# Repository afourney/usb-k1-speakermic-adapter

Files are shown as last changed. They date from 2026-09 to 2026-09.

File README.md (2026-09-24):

# USB K1 Speaker-Mic Adapter

A shoulder mic, a handful of breakout boards, and one USB cable. This adapter turns a Kenwood-style K1 radio speaker mic into a USB microphone, an amplified speaker, and two programmable push-to-talk buttons.

The excuse for building it was [Cabin Fever x86](https://github.com/afourney/cabin-fever-x86), a conversational text-adventure game played over a radio. If you're going to talk someone through an old text adventure, a proper shoulder mic feels like the right hardware. Squeeze the button, say your piece, and hear the reply through the same handset.

It also makes a satisfying physical interface for [Claude Code `/voice`](#claude-code) or [Teams](#microsoft-teams). Asking an agent to fix your code over a radio is optional. Saying “over” is between you and the transcription service.

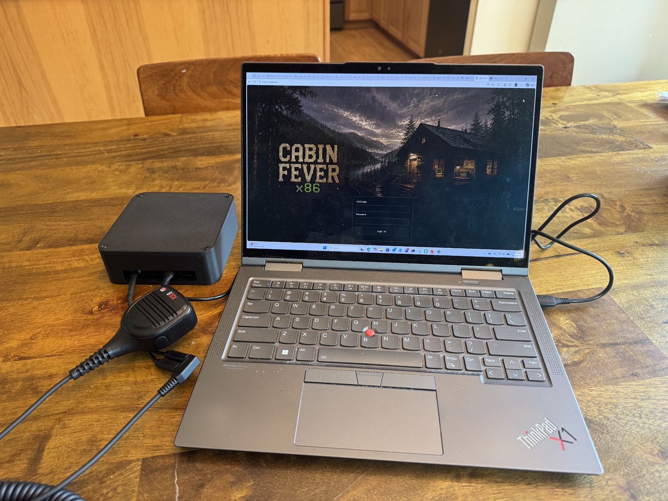
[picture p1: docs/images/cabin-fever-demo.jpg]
The finished adapter and BTECH speaker mic running Cabin Fever x86


*Ready to talk: the adapter and a BTECH QHM22D running Cabin Fever x86. Building with this mic? Read the [BTECH-specific wiring checks](docs/btech-qhm22d.md) first.*

## Video demo
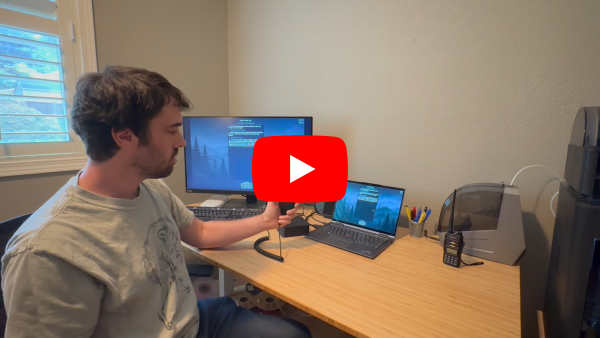
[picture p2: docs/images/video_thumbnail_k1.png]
Play Cabin Fever x86 with a real radio speaker mic! (https://www.youtube.com/watch?v=ixthcVkOpio)


## What's in the box?

The useful trick is to let ordinary USB devices do most of the work. A USB sound card handles microphone input and audio output. An LM386 module gives the little speaker enough drive to be heard. An Adafruit KB2040 running CircuitPython watches the two PTT buttons and presents them to the computer as keyboard keys. A tiny USB hub brings the audio and keyboard devices out through one cable. The supplied firmware sends **F13** from the main button and **Ctrl+Space** from the secondary button; both bindings are editable.

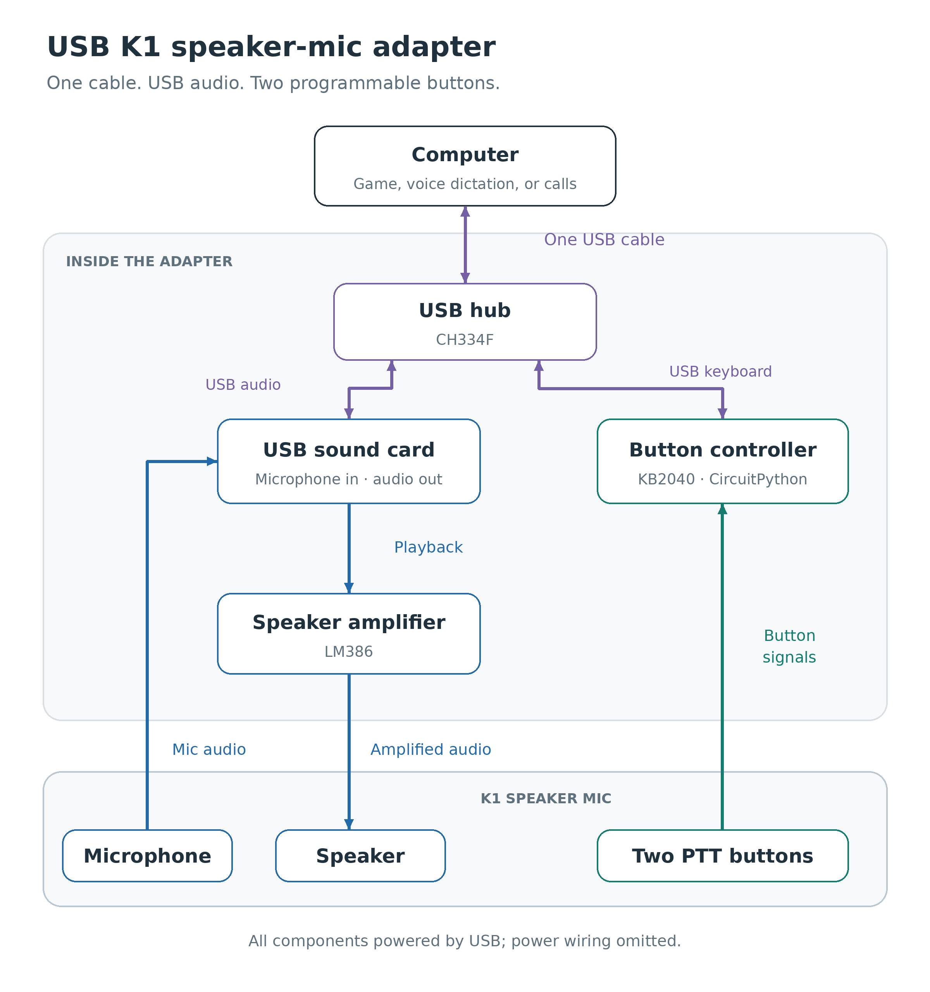
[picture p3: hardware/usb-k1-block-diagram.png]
Block diagram of the USB hub, sound card, LM386 amplifier, KB2040 button controller, and K1 speaker mic


*The sound card handles audio; the KB2040 turns button presses into keystrokes. Everything is powered from USB. Power wiring and individual connector contacts are left to the [schematic](#from-radio-accessory-to-usb-peripheral).*

## The K1 connector

The K1 connector has its roots in Kenwood's two-pin speaker/microphone interface: a 3.5 mm plug and a 2.5 mm plug mounted side by side. You'll find this Kenwood-style connection on handhelds from several manufacturers, notably the ubiquitous BaoFeng UV-5R. That shared connector gives us a ready-made supply of shoulder mics, earpieces, and other accessories to borrow for a USB project. [BTECH's compatibility list](https://baofengtech.com/product/qhm22d/) includes the UV-5R alongside models from Kenwood-style accessory families such as AnyTone, TYT, and Retevis.

A speaker mic already contains most of what we need: a microphone, a speaker, and a physical push-to-talk switch, all brought out through that pair of plugs. The audio connections are analog, and the PTT button closes a circuit. A compatible dual-PTT mic adds a second switch, giving us two independently readable buttons.

### K1 accessory pinout

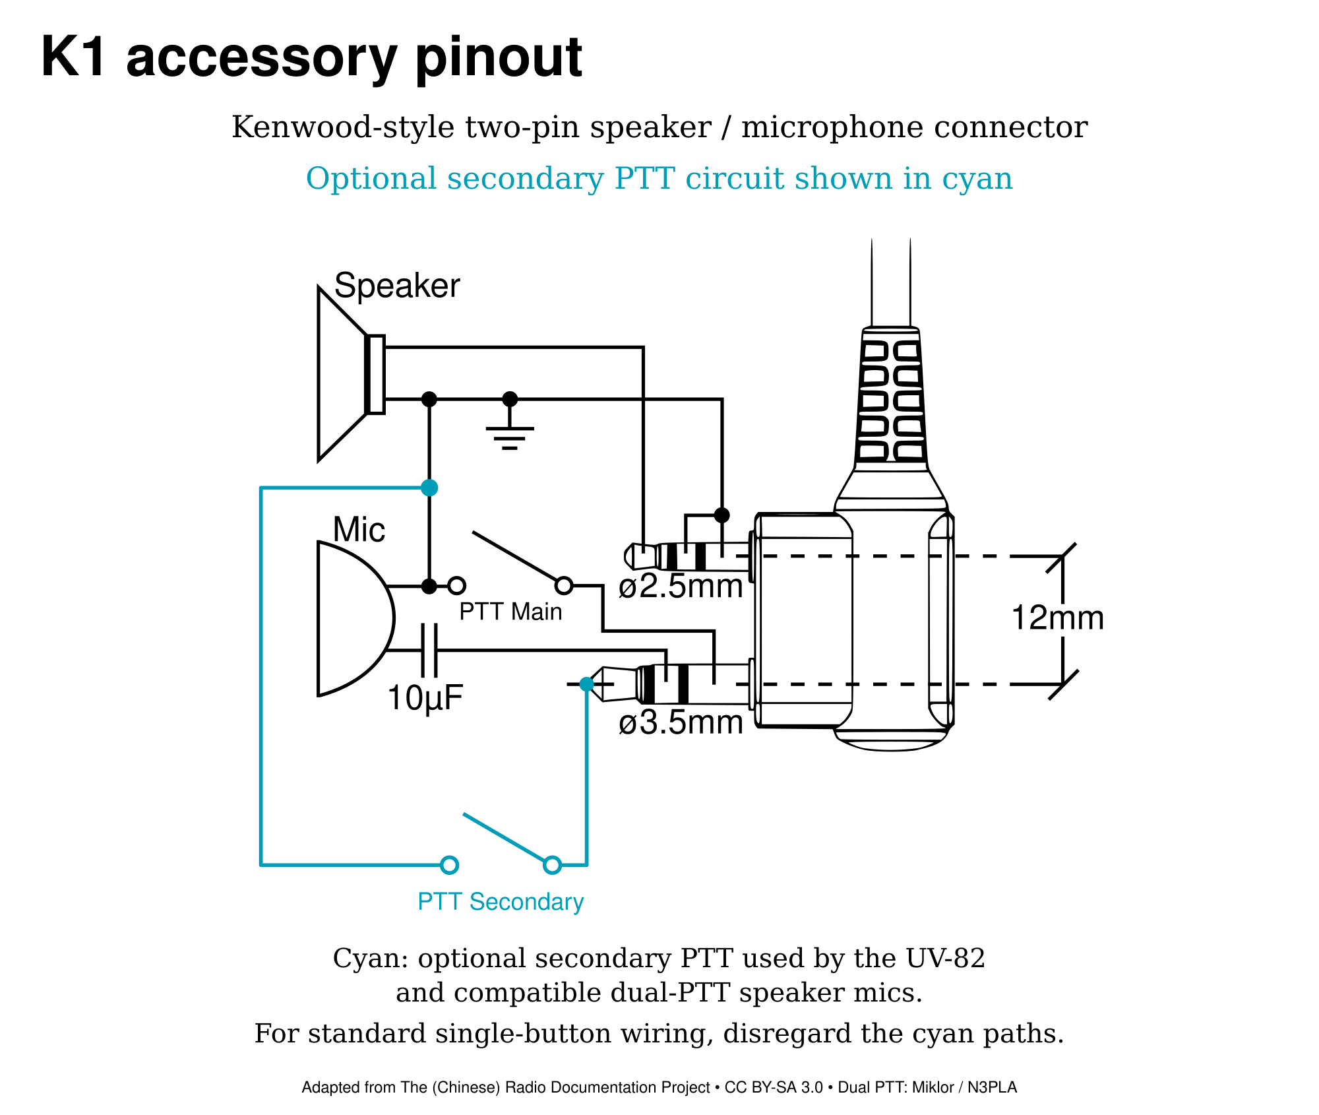
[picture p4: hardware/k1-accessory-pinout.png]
K1 accessory pinout: main PTT in black, optional secondary PTT in cyan


### From radio accessory to USB peripheral

Almost everything is already in place. The microphone can feed a suitable USB sound card's mic input, which supplies the electret bias. That leaves two jobs for the adapter.

First, the handset's **8 Ω speaker needs more drive than this USB sound card can provide directly**. It's a heavier load than a typical pair of headphones, and direct playback in this build was much too quiet. The LM386 module sits between the sound card's output and the speaker to supply the extra drive. It fits this build because it can drive a speaker with one side connected to **common ground**. This is important because the K1 handset shares that return between its speaker and PTT switches, ruling out bridge-output amplifiers such as the PAM8403, which actively drive both speaker terminals. Connecting such an amp's speaker “−” output to the adapter's common ground would short that output to ground.

The LM386 development boards used here come configured for approximately **200× voltage gain**. That's more than we need from a USB sound card and makes it easy to overdrive the amplifier. The LM386's default gain is **20×**; the board raises it with an external network between pins 1 and 8. See the [TI LM386 datasheet's gain-control section](https://www.ti.com/lit/ds/symlink/lm386.pdf#page=10). On the blue module used in this build, R1 is a 0 Ω jumper in the gain-boost network between pins 1 and 8. With power disconnected, **desolder R1 and leave its pads open**. This disconnects the boost network and returns the gain to **20×**. Check the board revision before modification since component labels are not universal.

While the sound card and amplifier take care of audio, we still need a way to report the handset's PTT switches to the computer—this is the second job of the adapter. Those buttons simply close electrical contacts that pull to ground. A microcontroller provides the missing link: it reads the switches and presents itself to the computer as a **USB HID keyboard**. Pressing a PTT button then looks like holding a keyboard key; releasing the button releases the key. Applications can use their [existing keyboard shortcuts](#using-it-with-applications) for push-to-talk, without needing a custom interface to the handset.

The **Adafruit KB2040** was chosen for a practical wiring detail: its **USB D+ and D− signals are broken out to accessible pads beside the USB-C connector**. That makes it straightforward to wire the USB data connection directly to the internal hub without soldering onto the connector's tiny contacts. Adafruit documents these pads in the [KB2040 pinout guide](https://learn.adafruit.com/adafruit-kb2040/pinouts). The board's RP2040 also provides native USB support and more than enough inputs for the two switches. Programming the board and choosing what each button sends are covered later in [firmware setup](#install-circuitpython-and-the-firmware).

The following wiring diagram shows the complete adapter, including the USB hub, sound card, LM386 module, KB2040, and K1 handset. The speaker mic block simplifies the handset's internal circuitry.

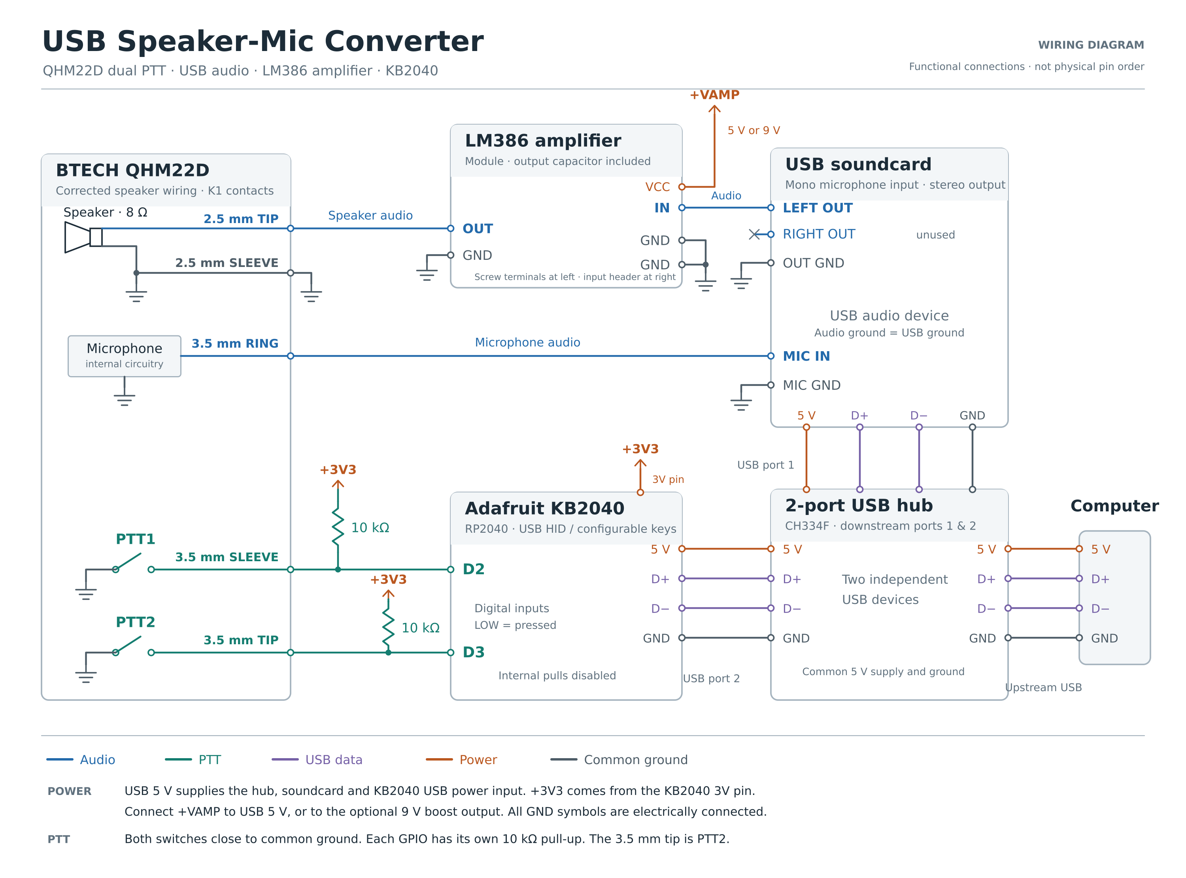
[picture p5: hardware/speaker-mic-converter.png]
USB speaker-mic converter wiring diagram


The build photo shows the LM386 at the top, the prototyping board in the middle, the KB2040 and USB hub below, and the separate USB audio adapter to the right. Follow the schematic and contact labels rather than copying wire colours from this overview.

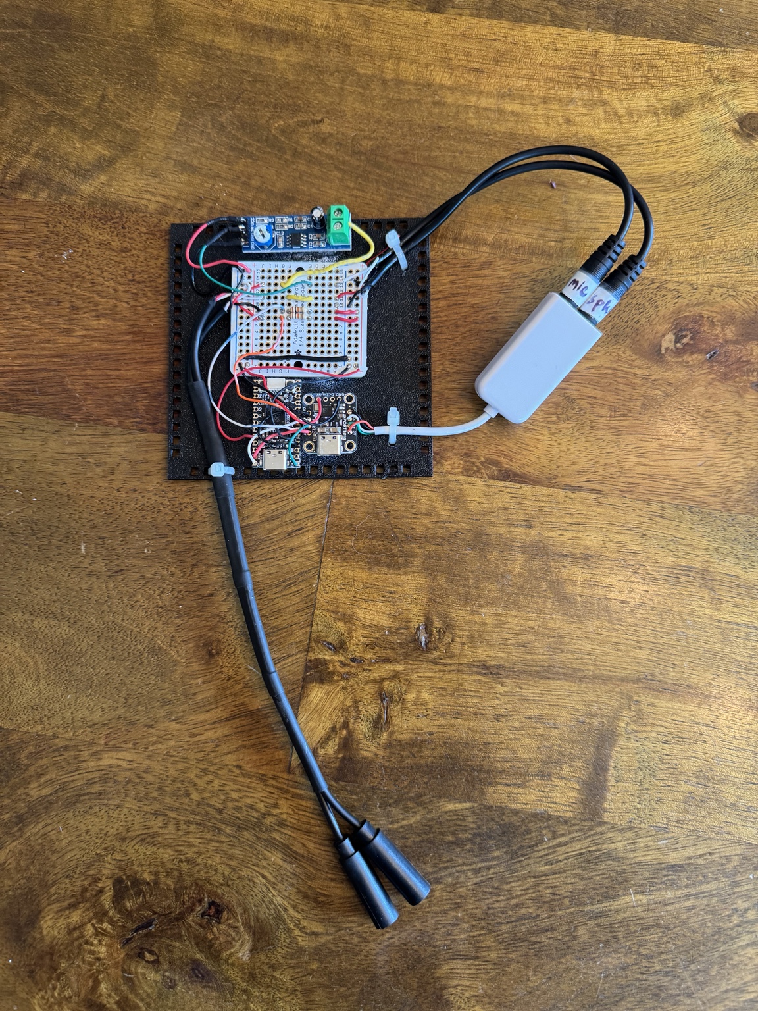
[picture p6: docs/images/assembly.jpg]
The module assembly before it is installed in the enclosure


## Parts and tools

Most of the work here is joining existing modules. These are the parts used in the documented build, with a reference part where the exact SKU wasn't recorded. Substitutions are fine if the electrical requirements match; check the board revision before copying a modification.

| Qty | Part | Purpose and selection notes |
| ---: | --- | --- |
| 1 | K1 Speaker Mic (e.g., [BTECH QHM22D dual-PTT speaker microphone](https://baofengtech.com/product/qhm22d/) · [Amazon](https://www.amazon.com/dp/B085HG7RX8)) | Kenwood K1-style two-plug connector, speaker, microphone, and one or two buttons. **Handset wiring can vary. [Test your handset before use!](#handset-wiring-check)** See the [BTECH-specific instructions](docs/btech-qhm22d.md) if using the QHM22D. |
| 1 | [Adafruit KB2040, product 5302](https://www.adafruit.com/product/5302) | RP2040 board for USB HID keyboard events. The supplied firmware uses its `D2`, `D3`, and `BUTTON` names. |
| 1 | [Adafruit CH334F Mini 2-Port USB Hub Breakout, product 5999](https://www.adafruit.com/product/5999) | Connects sound card and KB2040 to one upstream USB cable. Downstream connections are solder pads. |
| 1 | USB audio adapter with separate microphone and headphone jacks · [documented reference: Adafruit 1475](https://www.adafruit.com/product/1475) | Needs a microphone input suitable for an electret mic, including mic bias, and a ground-referenced headphone/line output. The exact SKU of the cabled adapter in the photos is unrecorded; do not assume its jack wiring from its appearance. |
| 1 | [LM386 audio amplifier module](https://protosupplies.com/product/lm386-audio-amplifier-module/) | The documented blue module has an input level trimmer and an output coupling capacitor. Use the capacitor-coupled output and common ground shown in the schematic. The prototype had its gain-setting **R1 removed**. |
| 2 | 10 kΩ resistors | One pull-up from each PTT input to the KB2040's regulated **3.3 V** output. Ordinary ¼ W resistors are sufficient. |
| 1 | [Adafruit Perma-Proto Quarter-sized Breadboard PCB, product 589](https://www.adafruit.com/product/589) | Carries the audio/PTT junctions and two resistors. One board is needed; the linked product is a pack of three. |
| 1 | One female **3.5 mm TRS** pigtail [Amazon](https://www.amazon.com/dp/B0C694NKJM) | Must expose all three contacts. If pigtails are not available, simply cut a short 3.5 mm extension cable and strip its wires. |
| 1 | One female **2.5 mm TRS** pigtail [Amazon](https://www.amazon.com/dp/B09V15J2MH) | Same as above. Cut an audio extension cable if pigtails are not available. |
| 2 | Short 3.5 mm male audio pigtails/breakouts [Amazon](https://www.amazon.com/dp/B0DMM3YFY1) | One for sound-card mic input; one for headphone output. This can be the other end of an extension cable if you cut one. |
| 1 | Upstream USB **data** cable | Computer to the hub's USB-C socket; choose the computer-end connector you need. |
| As needed | Heat-shrink, solder, cable ties, standoffs, screws | Keep USB data wiring short and paired. Insulate exposed connections and provide cable strain relief. |
| 1 | Nonconductive project box and mounting plate | Print the [supplied enclosure](docs/enclosure.md#print-the-enclosure), or size a project box around your assembled modules, plug bodies, cable bends, and lid clearance. |

The original diagram also shows an optional 9 V amplifier supply. **The instructions below use USB 5 V throughout.** A boost converter is unnecessary for the basic build; the prototype's 5 V/9 V comparison did not show a useful improvement for voice. Never feed 9 V into USB power, the KB2040, or a PTT input.

You will also need a multimeter with a low-ohms range, a soldering iron and flux, cutters/strippers, small screwdrivers, and a computer for copying files and testing USB audio. Fine tweezers and desoldering braid help with the amplifier's surface-mount gain resistor.

## Assembly Tips and Gotchas

### Handset wiring check

Handsets can be wired differently. Some BTECH QHM22D units, for example, have [been reported miswired](docs/btech-qhm22d.md) and need a repair before they can be used.

1. Unplug the handset from all equipment, including external earphones. Set the multimeter to resistance and touch the probes together to note the lead resistance.
2. Hold the main PTT button. Measure between the **3.5 mm sleeve** and **2.5 mm sleeve**: expect approximately **0 Ω**, plus probe/contact resistance.
3. Keep that same button held and move the probe from the **2.5 mm sleeve** to the **2.5 mm tip**. Expect the speaker-coil resistance—approximately **8–9 Ω** on the QHM22D used here.
4. Release the button and confirm that the sleeve-to-sleeve short disappears. For a compatible dual-PTT handset, also check **3.5 mm tip ↔ 2.5 mm sleeve**: pressing the secondary button should produce a near-zero reading, and releasing it should remove that short.

**Sleeve** means the metal contact nearest the cable; **tip** means the contact at the end of the plug. Use the numeric resistance reading: a continuity buzzer may beep for both 0 Ω and 8 Ω.

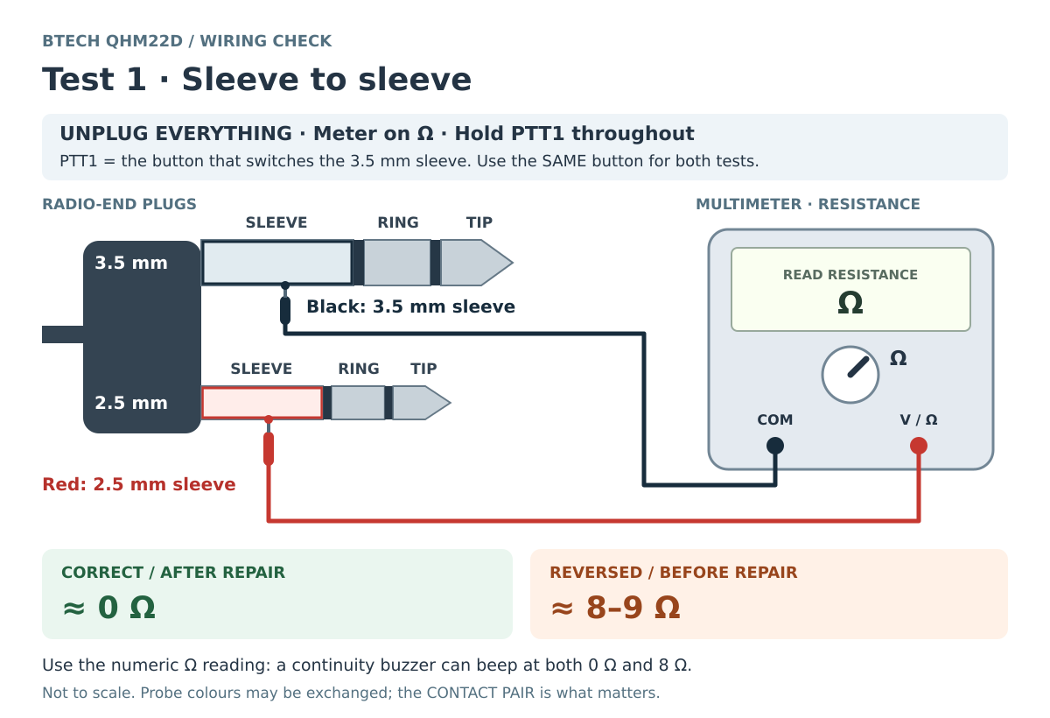
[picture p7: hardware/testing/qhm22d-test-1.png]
Test 1: probe the 3.5 mm sleeve and 2.5 mm sleeve while holding the main PTT


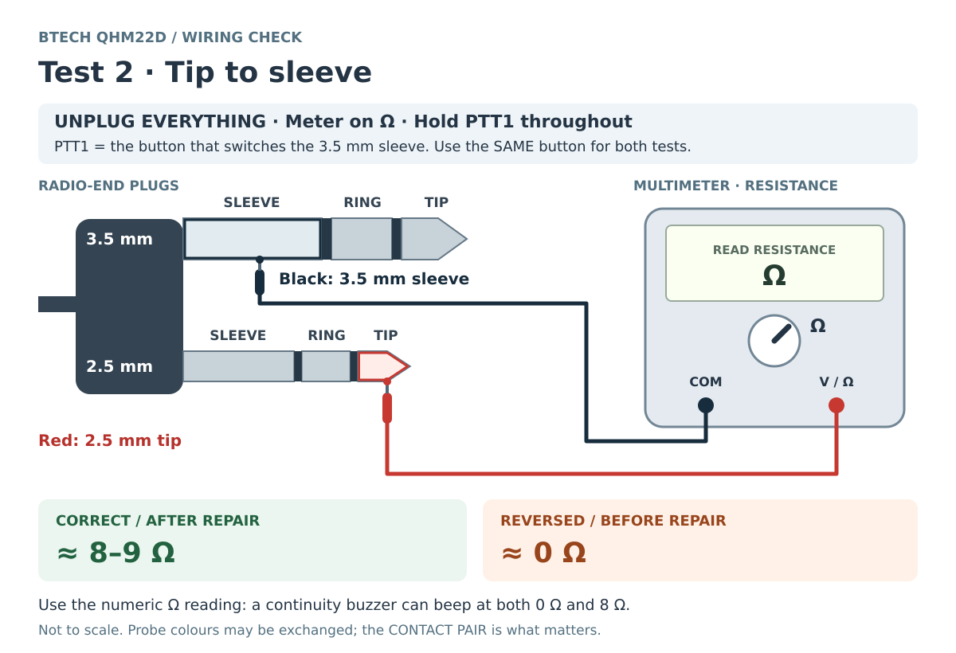
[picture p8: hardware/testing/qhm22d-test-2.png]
Test 2: keep the main PTT held and move the second probe to the 2.5 mm tip


*These diagrams show the BTECH QHM22D checks. If the two resistance readings are reversed, follow the [BTECH-specific repair instructions](docs/btech-qhm22d.md). Other handsets may have different speaker resistance or switching; investigate unexpected results before connecting them.*

### USB sound card preparation

The Adafruit CH334F Mini hub does not have any sockets for the client USB devices. The sound card and KB2040 must be wired to the hub's downstream pads. With USB disconnected, prepare the sound card by clipping the original USB cable and stripping the wires. Identify the four wires by continuity; use colour only as a clue. In my device, the colours were red = 5 V, black = GND, green = D+, and white = D−. It is important to check your own device, as the colours are not guaranteed to be the same. To do this, strip the wires on the connector end as well, and check continuity between the wires and the USB contacts. Use the following pinout to identify the contacts:

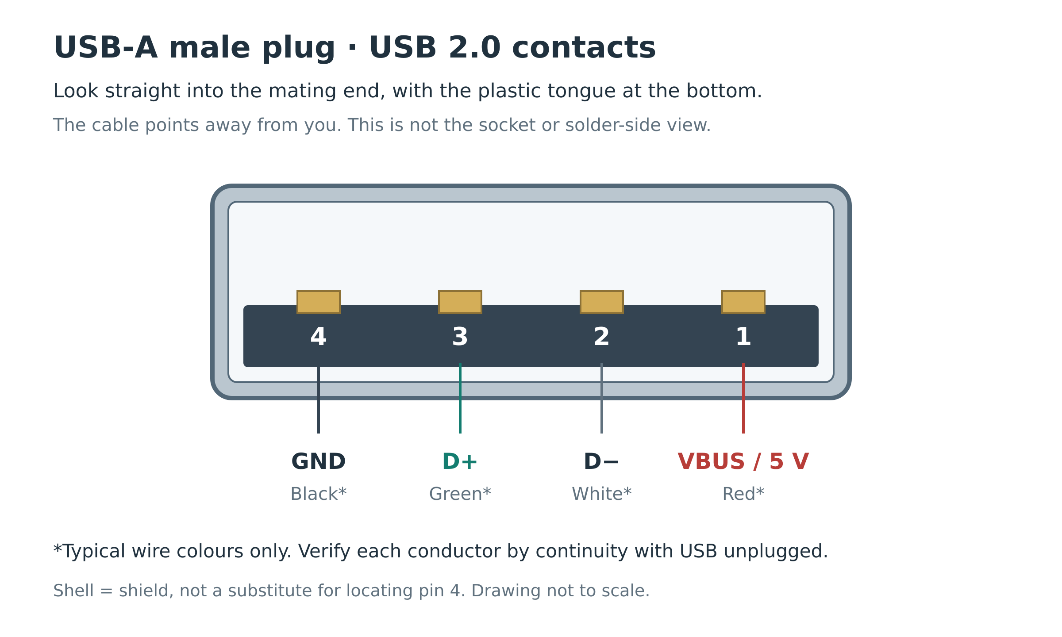
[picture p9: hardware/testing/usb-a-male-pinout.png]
USB-A male plug pinout, viewed into the mating end with the plastic tongue at the bottom


*View the male plug straight into its mating end, with the plastic tongue at the bottom and the cable pointing away from you. From left to right: pin 4 = GND, pin 3 = D+, pin 2 = D−, pin 1 = VBUS (5 V). Colours are typical, not guaranteed. Pin assignments and orientation follow the [USB 2.0 specification](https://www.usb.org/document-library/usb-20-specification), Table 6-1 and Figure 6-9.*

When connecting the sound card to the hub, keep the wires short and the D+/D− data pair twisted together. Do the same when connecting the KB2040 to the hub.

### Don't mix up your positive rails!

When wiring all the modules, note that all components share a common ground, but there are two positive rails: the USB 5 V and the KB2040's regulated 3.3 V. The LM386 module, USB hub, and USB devices (sound card and KB2040) are powered from the USB 5 V. On the KB2040, the `RAW` pin is on the USB-derived power rail, after the protection diode and fuse by default; see the [power pinout](https://learn.adafruit.com/adafruit-kb2040/pinouts). The KB2040 board has a 3.3 V regulator that then powers the onboard RP2040 microcontroller. **The two PTT inputs are pulled up to the KB2040's 3.3 V rail, <u>not the USB 5 V.</u>**

### Reduce excessive gain

As explained above, the LM386 development board starts at approximately **200× gain**. With power disconnected, **desolder the 0 Ω R1 jumper and leave its pads open** to disconnect the gain-boost path and return the LM386 to **20× gain**. Then set the onboard trimmer pot to about 1/3–1/2 of its range, and test the audio. If the sound is still harsh or distorted, reduce the trimmer further. The trimmer is not a gain control; it simply reduces the input level to the amplifier.

## Install CircuitPython and the firmware

Once CircuitPython is installed, changing what the buttons do is a text-file edit. The first flash takes a few more steps:

1. Download the stable [CircuitPython UF2 for **Adafruit KB2040**](https://circuitpython.org/board/adafruit_kb2040/).
2. With the board unplugged, hold **BOOT** while connecting its USB data cable. Release BOOT when the `RPI-RP2` drive appears. If the board is already wired to the hub, use that connection instead of a second USB cable.
3. Copy the `.uf2` file to `RPI-RP2`. The board restarts and exposes a drive named `CIRCUITPY`.
4. Download the [Adafruit CircuitPython library bundle](https://circuitpython.org/libraries) matching the major CircuitPython version in `CIRCUITPY/boot_out.txt`.
5. Copy the bundle's entire `adafruit_hid` folder into **`CIRCUITPY/lib/adafruit_hid/`**.
6. Copy [firmware/code.py](firmware/code.py) to **`CIRCUITPY/code.py`**. It belongs in the drive root, not inside `lib`. On Windows, show file extensions and check that it is not named `code.py.txt`.
7. Saving the file normally restarts the program. Later edits require only saving `code.py`, not flashing the UF2 again.

The supplied configuration is:

```python
PTT1_KEY = Keycode.F13
PTT2_KEY = (Keycode.LEFT_CONTROL, Keycode.SPACE)
BOOT_ALIASES_PTT1 = True
USE_INTERNAL_PULLUPS = False
DEBOUNCE_SECONDS = 0.020
POLL_SECONDS = 0.002
LOG_CHANGES = True
```

| Input | While held | On release |
| --- | --- | --- |
| PTT1 / D2 | F13 | Releases F13 |
| PTT2 / D3 | Left Ctrl + Space | Releases the chord |
| Onboard BOOT, after normal startup | F13 | Releases F13 when D2 is also released |

Change the keyboard mapping by adjusting `PTT1_KEY` and/or `PTT2_KEY`. For example, `PTT2_KEY = Keycode.SPACE` or `PTT2_KEY = Keycode.F14`. A Python tuple (e.g., `(Keycode.LEFT_CONTROL, Keycode.SPACE)`) represents a chord where both keys are held together. Here, pushing the button sends Ctrl+Space; releasing it releases both keys. The onboard BOOT button aliases PTT1 and is useful for testing the firmware before assembly or before any handset is attached. NOTE: as usual, holding BOOT at startup enters the bootloader.

Each input is debounced for 20 ms. When a PTT button is held, it holds keys as a keyboard would. The operating system may generate key-repeat events.

**External pull-ups are required by the default firmware.** For a temporary test of a bare KB2040 without the resistors, set `USE_INTERNAL_PULLUPS = True` before running it; restore `False` when both external 10 kΩ resistors are installed. Otherwise unconnected inputs float and can send unintended keys.

## Test the complete adapter

Now it's time to verify that the adapter works as intended. Start by checking the buttons and audio separately, then test them together with an application.

### Buttons first

1. Open the [W3C Keyboard Event Viewer](https://w3c.github.io/uievents/tools/key-event-viewer.html) and focus its input.
2. Hold PTT1: expect F13 down. Release it: expect F13 up. F13 does not type a visible character.
3. Hold PTT2: expect Control and Space with Ctrl active. Release it and check that **both** keys are released.
4. Hold both handset buttons; release them in each order. Each input should release without interfering with the other.

If these checks fail, use the [serial-console guide](docs/serial-console.md) to check the firmware's log messages for errors.

### Then audio

1. Select the USB sound card as the computer's input and output device, or select it explicitly in the application. Device names vary.
2. Record a short voice sample.
3. Start playback at low computer volume and low amplifier level. Slowly raise the level while listening to speech.
4. If the speaker sounds harsh or buzzy, turn down the computer output or amplifier input trimmer. The prototype was clear for voice but could clip on music.

## Mount it in an enclosure

The last component is a box to hide our wiring sins and protect the modules. The [enclosure folder](enclosure) includes STLs for the body, lid, and mounting plate with standoffs, plus a [Bambu Lab P1S 3MF project](enclosure/K1%20Adapter%20Box.3mf). You can also find the enclosure on [MakerWorld](https://makerworld.com/en/models/3343715-usb-k1-speaker-mic-adapter-enclosure#profileId-3799259). Test the complete assembly before closing it up. Mount each board on an insulating plate or standoffs, secure the audio adapter, and strain-relieve the USB and K1 cables. Leave room for the plug bodies and access to the amplifier trimmer and KB2040 reset/BOOT buttons. Keep solder joints clear of screws and the lid.

| Open enclosure | Finished cable entry |
| --- | --- |
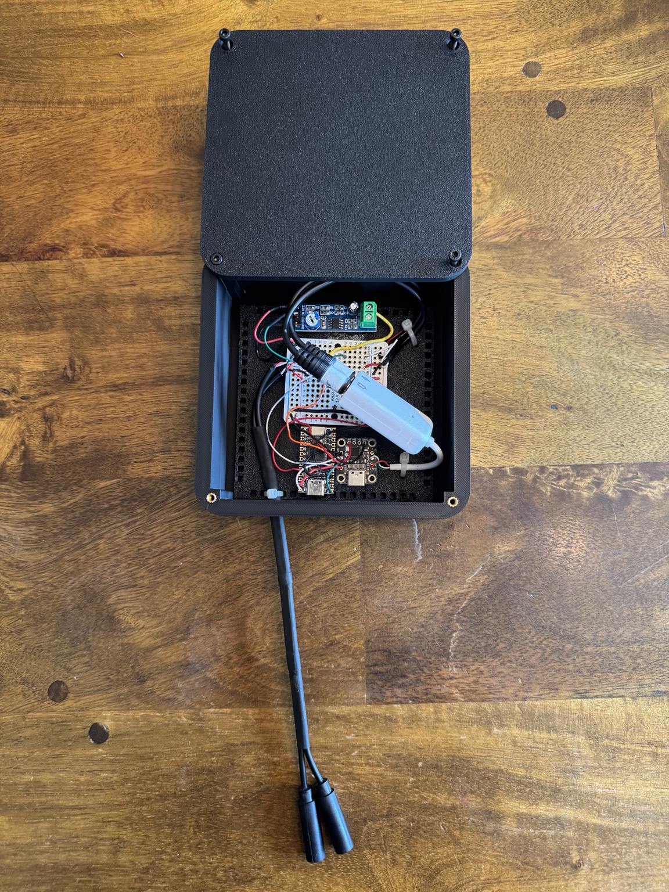
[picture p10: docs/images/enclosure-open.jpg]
Modules mounted inside the enclosure
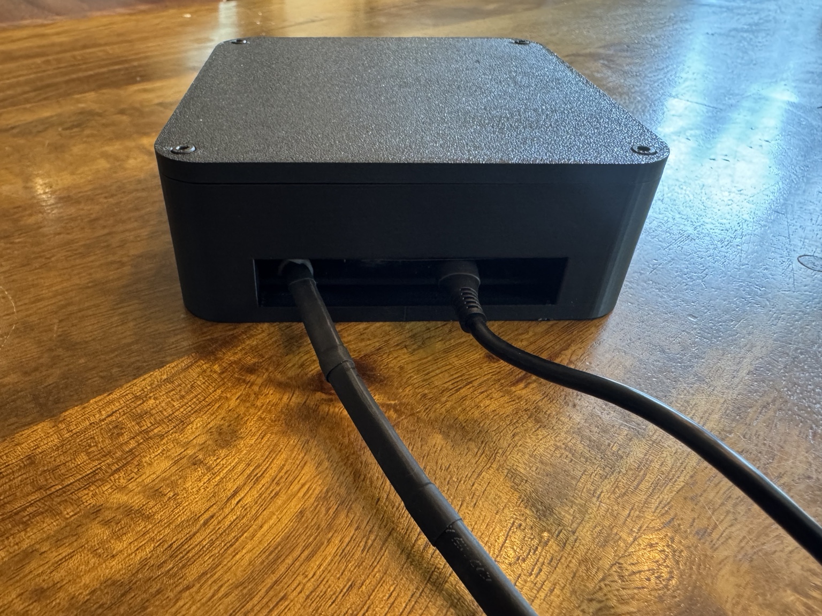
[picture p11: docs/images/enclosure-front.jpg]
Front opening with K1 breakout and USB cable
|  |  |

See [enclosure and mounting notes](docs/enclosure.md) for print settings and fitting the electronics. After mounting, repeat the button and audio tests while gently moving the cables. Nothing should disconnect, crackle, or generate a button press from cable movement.

## Using it with applications

At this point the computer sees audio hardware and a keyboard. Choose the USB sound card for audio, then tell the application what its PTT key should do. The application decides when to listen; the adapter supplies the sound and button presses.

### Cabin Fever x86

Use the adapter with [Cabin Fever x86](https://github.com/afourney/cabin-fever-x86). Select the USB microphone, grant the browser microphone permission, and route playback to the USB sound card. Match the handset's firmware binding to the game's current PTT control. Check that releasing the button ends the recording before a full session.

### Claude Code

Select the USB microphone as the host's input, enable `/voice hold`, and focus the prompt. Claude Code's default dictation key is Space; to test that path, set `PTT2_KEY = Keycode.SPACE` in the firmware. In hold mode, terminal key repeat must be enabled. See the official [voice dictation guide](https://code.claude.com/docs/en/voice-dictation).

To try the repository's **default Ctrl+Space** instead, merge the following into `~/.claude/keybindings.json` in the environment running Claude Code:

```json
{
  "bindings": [
    {
      "context": "Chat",
      "bindings": {
        "ctrl+space": "voice:pushToTalk"
      }
    }
  ]
}
```

This is a configuration example, **not a confirmed fix for Windows Terminal/WSL2**. Ctrl+Space did not work reliably in the original setup. Check terminal shortcut interception and the key received by Claude Code; use `/keybindings` and the [keybinding documentation](https://code.claude.com/docs/en/keybindings). A native browser receiving the HID chord does not prove that the terminal forwards it correctly. For WSL, also verify that its audio input works through WSLg.

#### Auto-submit on release

To send your dictated prompt when you release the PTT button, merge this into `~/.claude/settings.json` in the environment running Claude Code (inside WSL if that is where you run it). Keep any other settings already in the file:

```json
{
  "voice": {
    "enabled": true,
    "mode": "hold",
    "autoSubmit": true
  }
}
```

Hold the configured PTT button, speak, then release it. Claude Code finalizes the transcript and submits the prompt automatically if the transcript contains **at least three words**. Shorter transcripts stay in the input for manual submission with Enter. Set `"autoSubmit": false` to review every dictated prompt before sending. See the official [hold-to-record and auto-submit instructions](https://code.claude.com/docs/en/voice-dictation#hold-to-record).

### Microsoft Teams

Select the USB mic and speaker in Teams, then check the installed client's keyboard shortcuts for its press-and-hold temporary-unmute action. The firmware's Ctrl+Space binding is intended for clients that offer that shortcut. Test from a muted meeting with the intended window focus: hold to speak, release, and verify that the mute indicator returns. A single shared keybinding working in both Teams and Claude Code has **not been established for this build**.

## Troubleshooting

| Symptom | Check |
| --- | --- |
| Speaker works, but PTT fails or changes when headphones are inserted into the handset | For the BTECH QHM22D, follow the [wiring-test and repair guide](docs/btech-qhm22d.md). For other handsets, verify their wiring against the pinout. |
| Random key presses, or a button appears held | Both 10 kΩ pull-ups must connect to 3.3 V; confirm handset ground, correct socket contacts, and that the plugs are fully seated. |
| PTT is always active | Check that the K1 3.5 mm sleeve was not mistaken for common ground. |
| BOOT works but handset buttons do not | Check D2/D3 versus A2/A3, connector continuity, pull-ups, and each switch's resistance to ground. |
| Nothing appears over USB | Use a data cable; inspect upstream/downstream assignment, D+/D−, 5 V, and GND. Test each device separately. |
| Audio or keyboard disappears when the speaker gets loud | Reduce playback level; investigate supply sag, shorts, poor ground connections, and the USB source's current budget. |
| Speaker is extremely quiet | Check that playback passes through the powered LM386 and its level trimmer is not at minimum. |
| Harsh or distorted playback | Lower sound-card output and amplifier input level; confirm the intended gain modification. |
| No mic signal | Check the selected USB input, app permission, mic bias, K1 ring mapping, and whether the handset gates audio with its buttons. |
| Music is missing instruments or voices | Only the left channel is wired. Enable host mono output. |
| Firmware import error | Install the matching `adafruit_hid` folder under `CIRCUITPY/lib/`. |
| Keys work in a browser but not Claude Code | Check terminal key translation/interception and Claude Code's active binding. |
| Serial console is blank or PuTTY beeps | Follow [serial-console setup](docs/serial-console.md), including selecting Serial on the Session page. |

## References

### K1 diagram sources

- [The (Chinese) Radio Documentation Project's original SVG](https://github.com/radiodoc/uv-5r/blob/master/assets/images/kenwood-2pin-headset.svg) — Source artwork for the K1 diagram, licensed under CC BY-SA 3.0; the adapted PNG and SVG retain that license. This adaptation removes the +5 V label, adds the cyan secondary-PTT circuit, and revises the labels and captions.
- [The project's UV-5R manual](https://radiodoc.github.io/uv-5r/) — Original publication containing the accessory diagram.
- [Miklor's UV-82 technical notes](https://www.miklor.com/COM/UV_Technical.php) — Explains UV-82 dual-PTT operation and wiring.
- [Walt N3PLA's circuit diagram](https://www.miklor.com/COM/images/dualPTT-N3PLA.jpg) — Circuit reference for the added secondary-PTT wiring.
- [Kenwood's TH-F6A/TH-F7E manual, printed page 45](https://kasc.kenwood.com/files/images/products/product_id_268/file_category_10/TH-F6A_F7E_inst.pdf#page=50) — Corroborates the conventional speaker, microphone, and main-PTT contacts.
- [BaoFeng Tech's UV-82HP manual, printed page 19](https://baofengtech.com/wp-content/uploads/2020/09/UV82HP_Manual_ReducedSize.pdf#page=26) — Documents upper/lower-channel PTT operation; its generic accessory drawing does not show the second switch.

## Copyright and license

Copyright © 2026 Adam Fourney.

Licensed under the [MIT License](LICENSE), except for the adapted K1 accessory diagram, which retains its CC BY-SA 3.0 license as noted above. Please retain the copyright and license notices when redistributing this work.

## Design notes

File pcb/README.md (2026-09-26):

# K1 Carrier - Revision C (80 x 80 mm)

Open `kicad/k1-carrier-rev-c.kicad_pro` in KiCad 10. This is a standalone snapshot of the 80 x 80 mm, two-layer Revision C engineering project. Earlier revisions are not needed or included. See `PROJECT-SNAPSHOT.md` for package contents and Git tracking notes. Connector assignments are unchanged from Revision B; the modules and mounting holes have been repositioned for the smaller outline.

KiCad 10.0.6 checks: 0 ERC violations, 0 DRC violations, 0 unconnected pads, and 0 schematic-parity issues. Reports are saved in `preview/`. The schematic and assembly previews accompany the editable project. These checks do not replace the prototype release checks below.

## Connector Configuration (Retained From Revision B)

| Reference | Assignment |
|---|---|
| J1 | Board-mounted USB-A receptacle, Molex 67643-0910, replacing the USB wire pads |
| J2 | Sound-card microphone pigtail, moved to the right perimeter |
| J3 | Sound-card headphone-left pigtail, beside J2 |
| J4 | Six-circuit, right-angle Micro-Fit 3.0 header, Molex 43045-0600, replacing both K1 pigtail connectors |
| J5 | Retired; its K1 contacts are now in J4 |
| J6 | One 1x4, 2.54 mm interface: VCC, IN, GND, GND, replacing separate amplifier power and input connections |
| J7 | Retired; its audio input is now J6 pin 2 |
| J8 | LM386 capacitor-coupled output and optional ground, located to the left of R1/R2 |

The two PTT pull-ups remain 10 kohm to the **KB2040 3V / 3.3 V output**, not USB 5 V. Both switches continue to pull D2/D3 to common ground. Existing firmware assignments are preserved.

## Placement

The CH334F module's USB-C socket faces the top edge. The KB2040 sits below and to its right. The USB-A receptacle faces the right edge, with both sound-card audio pigtails below it. The Micro-Fit faces the bottom edge. The LM386 lies horizontally in the lower mounting area, with the combined input/power harness to its left. J8 sits above the amplifier, to the left of R1/R2. The amplifier outline has moved 8 mm right, leaving 10.5 mm from the J6 pad centerline to the module's left edge.

The USB-A socket is intended to face an **internal enclosure bay**, not necessarily an external wall. Allow room to the right of the carrier for the complete sound adapter, its plugs and cable bends. A short USB extension can relocate the adapter. No sound-card body dimensions are assumed. The enclosure footprint will need clearance beyond the carrier's 80 x 80 mm outline.

Leave clearance below J4 for its mating housing, wires and latch release. The Micro-Fit is not a panel-mount connector; strain-relieve the K1 harness at the enclosure. The LM386 mounting area is for electrically insulating double-sided foam mounting tape, not direct metal-to-PCB contact. Choose sufficient thickness to keep underside solder joints clear of the carrier, and check adhesion and temperature suitability on the actual module. The four amplifier tie-down holes have been removed; the four enclosure mounting holes remain.

The upper-right mounting hole is inset to clear the USB-A body. Relative to the board's upper-left corner, the four enclosure mounting holes are at (4,4), (58,4), (4,76), and (76,76) mm. J4 pin 6 and U2 pin 4 use solid ground-plane connections rather than thermal spokes.

## Connections

### J4: Entire K1 Harness

Use Molex **43025-0600** six-circuit receptacle housing and suitable Micro-Fit female crimp contacts/pre-crimped leads. Select contacts for the actual wire gauge and insulation diameter. Read the numbered cavities: the cable mating view and PCB top view are mirrored. Do not infer numbering from wire colours or the order in a photograph.

| Pin | K1 contact | Signal |
|---:|---|---|
| 1 | 3.5 mm tip | PTT2 / D3 |
| 2 | 3.5 mm ring | Microphone |
| 3 | 3.5 mm sleeve | PTT1 / D2; NOT ground |
| 4 | 2.5 mm tip | Speaker |
| 5 | 2.5 mm ring | Unconnected on carrier; may be left unpopulated |
| 6 | 2.5 mm sleeve | Common ground |

### J6: LM386 Input Harness

| Pin | Carrier signal | Module marking |
|---:|---|---|
| 1 | USB 5 V | VCC / VDD |
| 2 | Sound-card headphone left | IN |
| 3 | Common ground | GND |
| 4 | Common ground | GND |

This is a **single-row 2.54 mm pitch** connector/pad pattern, suitable for a four-position female jumper housing or soldered short ribbon wires. It is not a 2x2 IDC connector. The footprint is unshrouded, so check pin 1 before connecting power. Fit a standard male header to the carrier if using a detachable harness.

J6 is alongside the amplifier's left/input end. Its four-pad row is centered across the nominal 14 mm module width so the harness can run straight across. Pin 1 is at board-relative (3.5, 61.19) mm, with subsequent pins spaced 2.54 mm downwards. This is nominal alignment of a flexible harness, not a verified rigid board-to-board mating footprint. The legend is above the amplifier area and remains visible after mounting.

ProtoSupplies' connection photograph and schematic confirm the VCC/IN/GND/GND order and the shared grounds. The 2.54 mm pitch is corroborated by a matching-style module listing, not a dimensioned drawing of the exact purchased board. Confirm 7.62 mm from the first to fourth pin on the actual module before selecting a rigid mating connector. Keep this harness short. Both ground conductors may be connected; they do not represent isolated analog and power grounds.

### J8: LM386 Output

Pin 1 receives the module's capacitor-coupled OUT terminal. Pin 2 is common ground and may be left unwired: the amplifier is already grounded through J6, and J4 pin 6 has its own carrier-ground connection. No downstream connection relies on an external wire at J8 pin 2. Never connect an uncoupled LM386 IC output directly to the speaker.

### J1, J2 and J3: Sound Card

J1 USB-A: pin 1 = 5 V, 2 = D-, 3 = D+, 4 = ground. Both shell mounting tabs are bonded to common ground. The socket uses the installed KiCad library footprint for the Molex 67643 family; the selected BOM part is 67643-0910.

J2: pin 1 = microphone signal, pin 2 = ground. Identify the actual mic-bias contact of the selected sound card before wiring its male 3.5 mm plug.

J3: pin 1 = headphone LEFT (3.5 mm tip), pin 2 = ground (sleeve). Leave the right-channel ring disconnected. Enable mono output at the host if needed. The USB-A socket and the two pigtails together permit removing the sound adapter without cutting wires.

## Changed Parts

- J1: Molex **67643-0910**, right-angle through-hole USB-A receptacle.
- J4: Molex **43045-0600**, right-angle 2x3 Micro-Fit 3.0 PCB header with plastic locating peg.
- Mating J4 harness: Molex **43025-0600** housing plus six appropriate female contacts, or five if the unused cavity is unpopulated.
- J6: 1x4, 2.54 mm male header and matching four-position cable housing, or direct wires.
- J2, J3 and J8: 1x2, 2.54 mm solder pads/optional headers.
- U1: Adafruit KB2040 5302 with 2x 1x13 headers/sockets, including its extra USB data pads.
- U2: Adafruit CH334F Mini 2-Port Hub 5999 with 2x 1x4 headers/sockets. The four-port model is not interchangeable.
- R1/R2: 10 kohm, 1/4 W axial, 7.62 mm lead spacing.

## Prototype Status

### 3D Preview

Revision C includes local KiCad library STEP models for the two 1x13 KB2040 female sockets, two 1x4 hub female sockets, and both axial resistors. These are generic nominal parts, not selected socket manufacturer models. The library models retain the KiCad library license noted below. J4 now uses the manufacturer model `models/430450600.stp`, supplied by the user from Molex's 430450600 STEP archive, replacing the approximate placeholder. The model is rotated and offset to align its solder tails and locating peg with the footprint. Manufacturer CAD remains subject to Molex's terms. The mating cable housing, daughterboards, amplifier and loose wiring are not modeled. Optional headers on solder-wire connections are not populated in this preview. Confirm actual assembly clearances before fabrication.

Run `add_models.py` with KiCad Python to reapply models without changing routing; the main build also applies them. Reopen the saved PCB and its 3D viewer to refresh an already-open view.

This revision implements the connector and placement changes. It is **not a fabrication release** and does not include ordering Gerbers. As in Revision A, the USB routing is not a validated impedance-controlled differential-pair layout; it requires review against the chosen stackup and exact audio adapter. A clean KiCad DRC does not establish USB signal integrity, electrical noise performance or mechanical fit.

Before fabrication, confirm the amplifier connector pitch, socket stack heights, Micro-Fit mating/latch space, the audio adapter's full envelope and USB speed, and the enclosure dimensions. Check aggregate USB current and inrush with the amplifier load; the amplifier does not independently enumerate. The carrier adds no dedicated ESD protection to the exposed audio/PTT interfaces.

Power only through the hub USB-C. Do not connect another USB cable to the installed KB2040; remove it for independent programming, or program through the hub. Do not apply 9 V. Retain the original module's common-ground/capacitor-coupled amplifier arrangement and verify its gain modification to 20x before assembly.

The module symbols use passive interface pins. ERC checks connectivity but does not model internal regulators, audio behaviour, USB negotiation, or supply load. Read the final reports in `preview/` for the checks actually performed.

## References and Licenses

- Original adapter: https://github.com/afourney/usb-k1-speakermic-adapter
- KB2040 manufacturer CAD: https://github.com/adafruit/Adafruit-KB2040-PCB
- CH334F manufacturer CAD: https://github.com/adafruit/Adafruit-CH334F-Breakout-PCB
- Amplifier connections: https://protosupplies.com/wp-content/uploads/2018/12/LM386-Audio-Amplifier-Module-Connections.jpg
- Amplifier schematic: https://protosupplies.com/wp-content/uploads/2018/12/LM386-Audio-Amplifier-Module-Schematic.jpg
- Matching-style module pitch: https://fluxworkshop.com/products/bjaa100037-lm386-200x-gain-amplifier-lc-blue
- Micro-Fit drawing: https://www.molex.com/content/dam/molex/molex-dot-com/products/automated/en-us/salesdrawingpdf/430/43045/430450600_sd.pdf
- Cable housing: https://www.molex.com/en-us/products/part-detail/430250600
- USB-A drawing: https://www.molex.com/content/dam/molex/molex-dot-com/products/automated/en-us/salesdrawingpdf/676/67643/676430910_sd.pdf

Adafruit CAD: designed by Limor Fried/Ladyada for Adafruit Industries; Creative Commons Attribution/Share-Alike, with included license files. Support Adafruit and open-source hardware by purchasing their products. Original adapter copyright 2026 Adam Fourney, MIT, with separate artwork licensing described in its README. Standard connector footprints are copied from the installed KiCad library, licensed CC-BY-SA-4.0 with the KiCad libraries exception: https://www.kicad.org/libraries/license/

## Regeneration

The native KiCad project is editable and self-contained for symbols/footprints. The generation scripts only target this Revision C directory. Rebuilding overwrites Revision C, so preserve manual KiCad edits first. Run `build_carrier.py` and then `route_carrier.py` with KiCad's bundled Python, export a KiCad XML netlist to `preview/netlist.xml`, then run `sync_nets.py`. The scripts are retained for reproducibility, not required to open the project.

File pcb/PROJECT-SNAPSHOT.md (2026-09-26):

# Revision C source snapshot

Open `kicad/k1-carrier-rev-c.kicad_pro` in KiCad 10.

This folder is a standalone snapshot suitable for adding to a Git branch. It does not contain or initialize a Git repository. The editable board and schematic, project settings, local symbol and footprint libraries, five required model files, build scripts, reference geometry and attribution, and review previews are included. No files in another revision are required to open this project. No caches, editor locks or local UI preferences are included.

All PCB and footprint 3D model paths use `${KIPRJMOD}/models/`. Model files include the Molex 430450600 manufacturer STEP model and the USB-A, female socket and resistor KiCad library models. Third-party files retain their respective terms; see README and reference licenses before publishing. The manufacturer CAD is not relicensed as original project source.

The PCB is 80 x 80 mm. J8 is left of R1/R2, the LM386 mounting outline has moved right, and amplifier tie-down holes are removed for insulating mounting tape. PTT pull-ups remain on the KB2040 3.3 V rail. This is still an engineering draft, not a fabrication release.

The saved KiCad files are the primary editable deliverable. The Python scripts are optional regeneration tools: rebuilding replaces manual edits, and the generator currently expects the Windows KiCad 10 installation path for Python bindings and standard footprints. Included local models are preferred when reapplying models. See README for the regeneration sequence and prototype limitations.

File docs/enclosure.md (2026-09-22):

# Enclosure and mounting

[Back to the build guide](../README.md)

The prototype uses a rectangular enclosure with a removable lid and an internal mounting plate. The K1 female pigtails and upstream USB cable leave through the front opening. Print files are available in the [enclosure folder](../enclosure) and on [MakerWorld](https://makerworld.com/en/models/3343715-usb-k1-speaker-mic-adapter-enclosure#profileId-3799259).

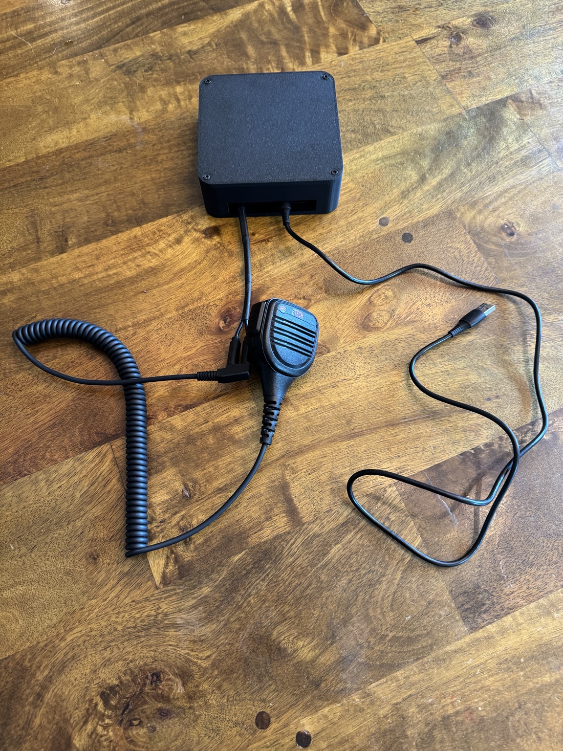
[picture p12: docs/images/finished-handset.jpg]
Complete handset, adapter enclosure, and USB cable


## Print the enclosure

| File | Contents |
| --- | --- |
| [K1 Adapter Box.3mf](../enclosure/K1%20Adapter%20Box.3mf) | Bambu Studio project configured for a **Bambu Lab P1S with a 0.4 mm nozzle**, with all parts arranged across three plates. |
| [K1 Adapter Box Body.stl](../enclosure/K1%20Adapter%20Box%20Body.stl) | Box body with the front cable opening and four corner screw holes. |
| [K1 Adapter Box Lid.stl](../enclosure/K1%20Adapter%20Box%20Lid.stl) | Removable lid. |
| [Base Plate and Standoffs.stl](../enclosure/Base%20Plate%20and%20Standoffs.stl) | Internal mounting plate and separate standoffs, grouped in one STL. |

The body measures **125 × 125 × 40 mm** in the supplied mesh; the lid is **125 × 125 × approximately 5 mm**.

For the P1S, download the 3MF and open it as a project in Bambu Studio to retain its settings and part placement. Plate 1 contains the body, plate 2 the lid, and plate 3 the mounting plate and standoffs. The saved settings use 0.20 mm layers, three walls, 20% infill, enabled supports, a Textured PEI Plate, and an eSUN PLA+ filament preset. Confirm the filament and build plate match your setup, then slice and preview each plate before printing. The project contains models and settings, rather than pre-sliced G-code.

For another printer or slicer, use the individual STLs at **100% scale in millimetres** and configure the print for your machine. The 3MF places the body open-side up, the lid flat, and the mounting plate and standoffs flat on the bed.

## Mount the electronics

Dry-fit the printed parts and electronics before fastening anything. If using a different project box, the same layout and clearance checks apply.

1. Arrange the amplifier, prototyping board, KB2040, hub, and audio adapter on the mounting plate. If using a different box, establish this layout before choosing its size.
2. Include the full length of inserted audio and USB plugs in your measurements. Leave room for their cables to bend without pushing sideways on sockets.
3. Check lid clearance above the tallest part, including screw heads, cable ties, and any underside solder joints.
4. Plan access to the amplifier trimmer and the KB2040 BOOT/reset buttons. The hub connection can carry firmware updates, but physical button access is still useful for recovery.
5. Fix boards with suitable standoffs or nonconductive mounts. Secure the cased audio adapter separately so its mass cannot tug on USB solder joints.
6. Fit strain relief at cable exits. A pull on the outside cable should be taken by the enclosure or mounting plate, not by a PCB pad.
7. Keep analog microphone wiring away from USB data wiring and the amplifier power/output loop where practical.
8. Inspect for exposed conductors touching mounting hardware, then repeat the functional tests after assembly.

The two flying K1 sockets preserve access to the handset's existing plug. They also avoid needing to reproduce its exact two-plug spacing in a drilled panel.

Open prototype enclosure

## Design changes

The STL files provide the printable meshes, and the 3MF preserves the slicer project. Editable source CAD is not included. When contributing revisions, include the source CAD if available and record any changes to fasteners, clearances, or print settings.

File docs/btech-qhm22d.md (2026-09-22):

# BTECH QHM22D: wiring test and repair

[Back to the build guide](../README.md)

These instructions apply to the **BTECH QHM22D** used in this build. Its yellow and brown cable wires arrived reversed, putting the PTT return on the speaker signal contact. Test your unit before connecting it; do not swap wires on a unit that already passes. This repair is not a general requirement for K1 speaker mics.

On this handset, **PTT Main** is the large side button (`PTT1` / `D2`), and **PTT Secondary** is the small top button (`PTT2` / `D3`). See the [K1 accessory pinout](../README.md#k1-accessory-pinout) for the contact assignments and original wiring sources.

## 1. Test the speaker mic before building

The defect is easy to miss: the internal speaker can still make sound with reversed leads. The important problem here is where the PTT switch connects, not just acoustic polarity.

1. Disconnect the handset from everything: radio, adapter, USB, and any external earphones.
2. Set the meter to resistance, preferably its lowest useful range. Touch the probes together and note the lead resistance.
3. Identify the **2.5 mm tip**, **2.5 mm sleeve**, and **3.5 mm sleeve** on the handset's radio plug.
4. Measure between the two sleeves while holding the PTT button associated with the **3.5 mm sleeve**. On a dual-button handset, try each button separately to identify it; this guide calls that input PTT1.
5. Keep that same button pressed and measure between the **2.5 mm tip** and **3.5 mm sleeve**.
6. Compare the pair of readings with the table. Use actual resistance values: a continuity buzzer may beep for both 0 Ω and 8 Ω.

### Test 1: sleeve to sleeve

Hold PTT1. Touch the **black probe to the 3.5 mm sleeve** and the **red probe to the 2.5 mm sleeve**. A correctly wired unit reads approximately **0 Ω**; the reversed unit reads the speaker's resistance, approximately **8–9 Ω**.

Test 1 probe placement: 3.5 mm sleeve to 2.5 mm sleeve, with correct and reversed resistance readings

### Test 2: move one probe to the tip

Keep **the same PTT button held** and the **black probe on the 3.5 mm sleeve**. Move only the **red probe to the 2.5 mm tip**. The readings should exchange: approximately **8–9 Ω** when correctly wired, or approximately **0 Ω** on the reversed unit.

Test 2 probe placement: 3.5 mm sleeve to 2.5 mm tip, with correct and reversed resistance readings

The drawings show the **radio-end plugs**, not the handset's headphone socket. Touch one exposed metal segment with each probe; avoid bridging a black insulating band. The probe colours are for clarity—either polarity works for these two resistance checks. Click either diagram to open its editable SVG.

| Measurement, with PTT1 held | Correct wiring | Reversed wiring on this unit |
| --- | --- | --- |
| 2.5 mm **sleeve** ↔ 3.5 mm sleeve | Approximately **0 Ω** plus probe/contact resistance | Approximately **8 Ω**, through the speaker |
| 2.5 mm **tip** ↔ 3.5 mm sleeve | Approximately **8 Ω**, through the speaker | Approximately **0 Ω** |

The speaker in this build measured around **8–9 Ω**; treat that as a recognizable speaker-coil reading, not a precision acceptance limit. Swapping the meter probes does not change which test is which—the distinction is **tip versus sleeve on the 2.5 mm plug**.

Release PTT1 and verify that the sleeve-to-sleeve short disappears. Also identify PTT2 by testing **3.5 mm tip ↔ 2.5 mm sleeve**: the repaired handset should change from open/high resistance to near zero when its other button is held. If the switching or resistance pattern differs substantially, trace the accessory before using this wiring plan.

### Reports of the same problem

- [Amazon review: “repair the factory defect and then it works great,” September 4, 2022](https://www.amazon.com/gp/customer-reviews/RETJVNP2EQFWO). The reviewer describes reversed speaker leads and loss of PTT when external headphones are connected. Amazon may require sign-in; the review's supplied screenshot was used as a reference and is not redistributed here.
- [Independent repair report: “Comms at Home, QHM22D question”](https://www.reddit.com/r/Baofeng/comments/123nzs1/comms_at_home_qhm22d_question/). The discussion links that exact Amazon review, and the owner reports that the repair worked.
- [Earlier first-hand symptom report](https://www.reddit.com/r/Baofeng/comments/lg8wdt/help_baofeng_qhm22d_dual_ptt_speaker_mic_stops/). The original post is deleted, so the remaining thread provides limited context; it is not proof of a particular internal fault.
- [Adam Fourney's review on BTECH's product page](https://baofengtech.com/product/qhm22d/#reviews), September 8, 2026, records this build's resistance readings and repair. This is the same unit documented here, not an additional independent sample.

These are reports about particular units, not evidence that every QHM22D is wired incorrectly.

## 2. Repair the yellow/brown reversal, if present

Only do this if your measurements identify the reversal. Returning a defective unit is also an option.

1. With the handset completely disconnected, remove the two screws on its back.
2. Carefully open the housing without pulling on the speaker or microphone leads. Photograph the original wiring.
3. Locate the **lower row of cable connections** on the PCB, beside the cable entry. On the photographed board the labels read `SP−`, `SP+`, `PTTB`, `MIC+`, and `PTTA`.
4. Desolder the **yellow** lead from `SP−` and the **brown** lead from `SP+`. Let the solder melt before lifting each wire; do not pull up a pad.
5. Reconnect **brown to `SP−`** and **yellow to `SP+`**. Leave the adjacent green, red, and black cable wires alone. Leave the separate red/black wires to the speaker and microphone at the top of the board alone too.
6. Inspect for solder bridges, loose strands, damaged insulation, and a secure cable entry. Wire colours can change between revisions; the labels and measurements take precedence.
7. Repeat both PTT1 resistance measurements and the PTT2 switching check **before reconnecting anything powered**. The two PTT1 readings should now match the correct-wiring column.
8. Refit the housing without pinching wires or disturbing its seal.

| Before: factory reversal on this unit | After: corrected cable connections |
| --- | --- |
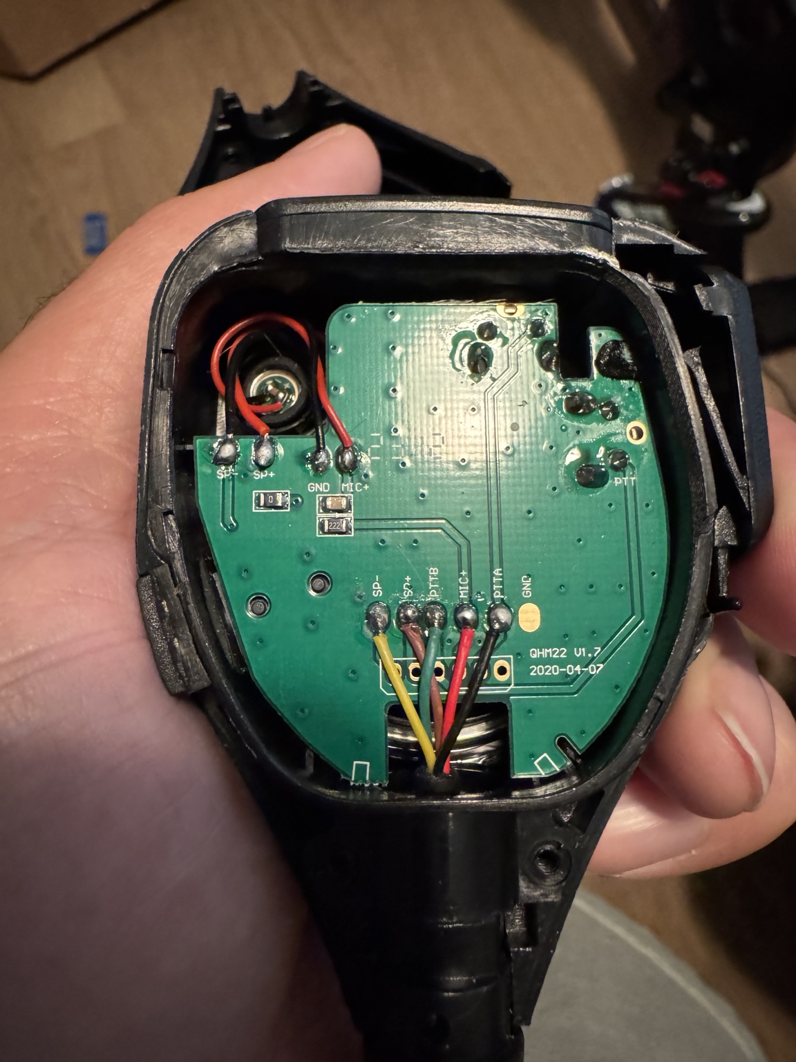
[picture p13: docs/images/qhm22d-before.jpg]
Before repair: yellow on SP minus, brown on SP plus
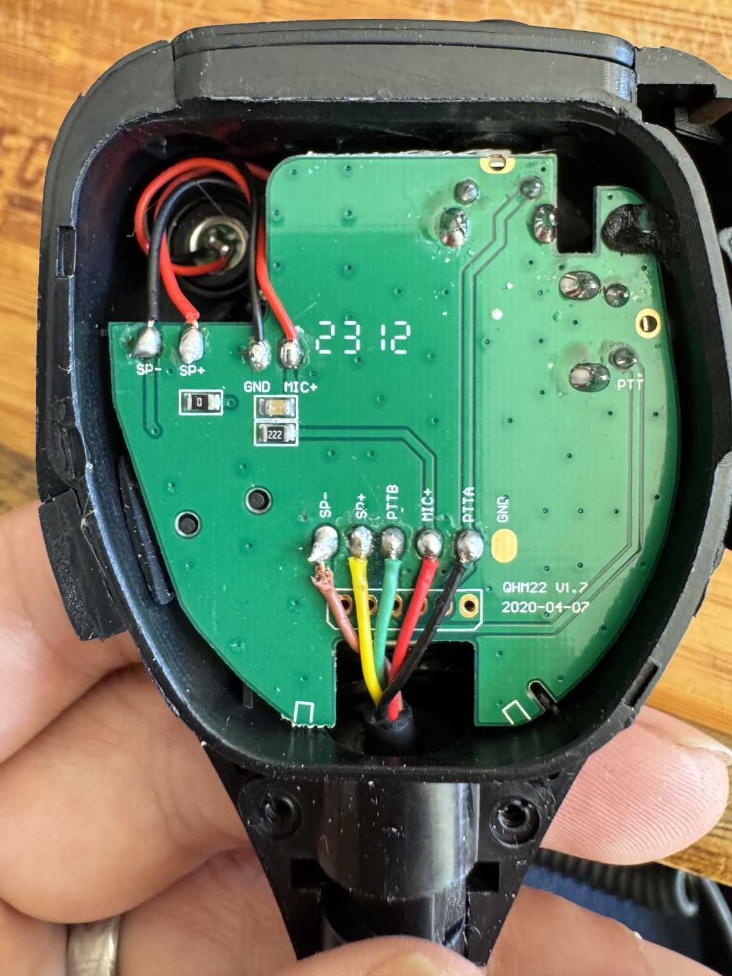
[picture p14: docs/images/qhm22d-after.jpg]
After repair: brown on SP minus, yellow on SP plus
|  |  |
| `SP−`: yellow · `SP+`: brown | `SP−`: brown · `SP+`: yellow |

Both pictures show the actual handset used in this project. The swap is on the **incoming cable pads at the bottom**, not the speaker's own two wires at the top.

[Continue with adapter assembly](../README.md#assembly-tips-and-gotchas)

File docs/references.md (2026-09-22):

# References and evidence

[Back to the build guide](../README.md)

Links checked while preparing this repository on September 22, 2026. The source notes distinguish a reported defect from verified electrical requirements and this prototype's own observations.

## QHM22D wiring reversal

| Source | What it establishes |
| --- | --- |
| [Amazon customer review RETJVNP2EQFWO](https://www.amazon.com/gp/customer-reviews/RETJVNP2EQFWO) | The supplied screenshot identifies a September 4, 2022 review titled “repair the factory defect and then it works great.” It describes swapping reversed speaker leads to restore operation with external headphones. Direct Amazon retrieval failed during preparation; the exact permalink is independently linked by the Reddit thread below. The screenshot is not included. |
| [Comms at Home, QHM22D question](https://www.reddit.com/r/Baofeng/comments/123nzs1/comms_at_home_qhm22d_question/) | Independent owner describes PTT failure with an external headset, receives the Amazon repair link, and reports success after soldering the repair. Other comments suggest different causes, so this supports testing a unit rather than assuming a universal defect. |
| [Earlier QHM22D headset/PTT report](https://www.reddit.com/r/Baofeng/comments/lg8wdt/help_baofeng_qhm22d_dual_ptt_speaker_mic_stops/) | Related first-hand discussion, but the original post is deleted. Limited corroboration of the symptom, not confirmation of the yellow/brown fault. |
| [BTECH QHM22D product page and customer reviews](https://baofengtech.com/product/qhm22d/#reviews) | Product identity and Adam Fourney's September 8, 2026 account of the same photographed unit. It records the approximately 0 Ω/8 Ω readings and repair; it is not an independent sample or a manufacturer defect notice. |
| [Before photograph](images/qhm22d-before.jpg) / [after photograph](images/qhm22d-after.jpg) | Original photos of this build: cable-entry SP− changes yellow → brown; SP+ changes brown → yellow. The board is marked QHM22 V1.7, 2020-04-07. |

## Hardware and firmware

| Source | Use |
| --- | --- |
| [Miklor technical diagrams](https://www.miklor.com/COM/UV_Technical.php) | K1 speaker/microphone contact assignments and sleeve-to-sleeve PTT, with separate dual-PTT drawings. Background for interpreting measurements, not evidence of a BTECH manufacturing defect. |
| [Adafruit KB2040 product](https://www.adafruit.com/product/5302) and [pinout](https://learn.adafruit.com/adafruit-kb2040/pinouts) | Board identity, D2/D3, regulated 3V, BOOT input, USB data pads, and power-path distinctions. |
| [CH334F hub product](https://www.adafruit.com/product/5999) and [pinout](https://learn.adafruit.com/adafruit-ch334f-mini-4-port-usb-hub-breakout/pinouts) | Two downstream USB connections and their wiring. The shared guide covers both 2-port and 4-port boards. |
| [Adafruit USB audio adapter 1475](https://www.adafruit.com/product/1475) | Reference part linked during planning. This does not identify the exact cabled adapter visible in the final photos. |
| [ProtoSupplies LM386 module](https://protosupplies.com/product/lm386-audio-amplifier-module/) | Module source discussed during the build. The earlier product description specified an LM386M-1, 4–12 V operation, input trimmer, and 200× gain. Live retrieval returned HTTP 403 during preparation. |
| [TI LM386 datasheet](https://www.ti.com/lit/ds/symlink/lm386.pdf) | Gain-setting principle and output coupling requirement. It does not assign the module-specific reference designator R1. |
| [CircuitPython for KB2040](https://circuitpython.org/board/adafruit_kb2040/) and [library bundle](https://circuitpython.org/libraries) | Runtime and `adafruit_hid` installation. |
| [W3C Keyboard Event Viewer](https://w3c.github.io/uievents/tools/key-event-viewer.html) | Host-side inspection of keydown and keyup events. |

## K1 accessory diagram sources

The [README pinout section](../README.md#k1-accessory-pinout) embeds the [PNG](../hardware/k1-accessory-pinout.png) and links the [editable SVG](../hardware/k1-accessory-pinout.svg).

- [Original SVG, The (Chinese) Radio Documentation Project](https://github.com/radiodoc/uv-5r/blob/master/assets/images/kenwood-2pin-headset.svg), from the [UV-5R manual](https://radiodoc.github.io/uv-5r/). The adapted PNG and SVG retain [CC BY-SA 3.0](https://creativecommons.org/licenses/by-sa/3.0/). Changes: removed +5 V, added cyan secondary PTT, revised labels and captions.
- [Miklor UV-82 dual-PTT instructions](https://www.miklor.com/COM/UV_Technical.php), [connector photograph](https://www.miklor.com/COM/images/dualPTT.jpg), and [Walt N3PLA circuit](https://www.miklor.com/COM/images/dualPTT-N3PLA.jpg): main PTT switches the 3.5 mm sleeve to the 2.5 mm sleeve; secondary PTT switches the 3.5 mm tip to that same ground.
- [Kenwood TH-F6A/TH-F7E manual, printed page 45](https://kasc.kenwood.com/files/images/products/product_id_268/file_category_10/TH-F6A_F7E_inst.pdf#page=50): conventional main-PTT and audio contacts; this model uses the 3.5 mm tip for 3.5 V, not secondary PTT.
- [UV-82HP manual, printed page 19](https://baofengtech.com/wp-content/uploads/2020/09/UV82HP_Manual_ReducedSize.pdf#page=26): upper/lower-channel PTT operation. Its accessory illustration is a generic single-PTT drawing, not evidence for the secondary-PTT pin assignment.

## Applications

- [Cabin Fever x86](https://github.com/afourney/cabin-fever-x86): companion game; consult its current controls for the PTT binding.
- [Claude Code voice dictation](https://code.claude.com/docs/en/voice-dictation) and [keyboard shortcuts](https://code.claude.com/docs/en/keybindings): `/voice hold`, the `Chat` context, and the `voice:pushToTalk` action. The repository's Ctrl+Space example has not been established as working in the original Windows Terminal/WSL2 setup.
- Teams guidance is intentionally conditional on the installed client's shortcut list. A current official Teams page could not be retrieved during preparation; there is no claim of a verified universal Teams/Claude binding.

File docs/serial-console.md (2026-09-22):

# Serial console and firmware troubleshooting

[Back to the build guide](../README.md)

The KB2040's CircuitPython console prints button changes and Python errors. It uses USB serial independently of the audio and HID keyboard interfaces.

## Connect on Windows

1. Start the board normally, without holding BOOT. `CIRCUITPY` should be visible.
2. Open **Device Manager → Ports (COM & LPT)**. Identify the USB serial port by unplugging/reconnecting the board after pending writes finish. `COM7` was used during development; use the port actually shown on your computer.
3. Open [PuTTY](https://www.chiark.greenend.org.uk/~sgtatham/putty/latest.html).
4. On the **Session** page, choose the **Serial** connection-type radio button. Selecting “Serial” in the left navigation alone does not change the connection type.
5. Enter the COM port and speed **115200**. Under **Connection → Serial**, select 8 data bits, 1 stop bit, no parity, and **no flow control**.
6. Click **Open**. Close any other program that already owns that serial port.

If PuTTY is on PATH, the equivalent Windows command is:

```bat
putty.exe -serial COM7 -sercfg 115200,8,n,1,N
```

## Read the output

An initially blank console is normal: earlier log messages are not replayed. Press a handset button, or press **Ctrl+C**, then Enter if prompted, to reach the `>>>` REPL. **Ctrl+D** restarts the program and shows its startup message or traceback.

With the supplied firmware, normal output looks like:

```text
PTT ready.
PTT1: DOWN PTT2: up
PTT1: up PTT2: up
PTT1: up PTT2: DOWN
PTT1: up PTT2: up
```

Ctrl+C stops the PTT program until Ctrl+D or reset. A resulting `KeyboardInterrupt` is expected. These labels reflect the configured held keys; use a host keyboard-event viewer to verify the actual HID behavior.

## Common failures

| Failure | Resolution |
| --- | --- |
| `ImportError` for `adafruit_hid` | Copy the whole matching bundle folder to `CIRCUITPY/lib/adafruit_hid/`. |
| Syntax error after editing | Check indentation and the exact names `Keycode.SPACE` and `Keycode.LEFT_CONTROL`. |
| Wrong pin names | This file targets KB2040. Other RP2040 boards require different CircuitPython firmware and possibly different `board` names. |
| Only `RPI-RP2` appears | This is the UF2 bootloader. Install CircuitPython or restart without holding BOOT. |
| Access denied opening COM port | Close other serial monitors and verify the current COM number. |
| PuTTY beeps instead of opening the console | Select the Serial radio button on the Session page. |
| PuTTY beeps when pressing the PTT button | The HID keystroke may be going to PuTTY. Focus the browser key-event viewer while testing keys. |

During an unsoldered bench test, set `USE_INTERNAL_PULLUPS = True`; in the assembled build use the two external 10 kΩ pull-ups and the shipped `False` setting. BOOT always uses its own internal pull-up.

## Updating the program

Back up an existing program before replacing it. Edit `CIRCUITPY/code.py` as UTF-8 plain text. Saving normally triggers a reload. Installing a new runtime UF2 is unnecessary for ordinary keybinding changes.

References: [KB2040 CircuitPython installation](https://learn.adafruit.com/adafruit-kb2040/circuitpython), [CircuitPython libraries](https://learn.adafruit.com/welcome-to-circuitpython/circuitpython-libraries), and [PuTTY serial documentation](https://the.earth.li/~sgtatham/putty/0.83/htmldoc/Chapter3.html#using-serial).

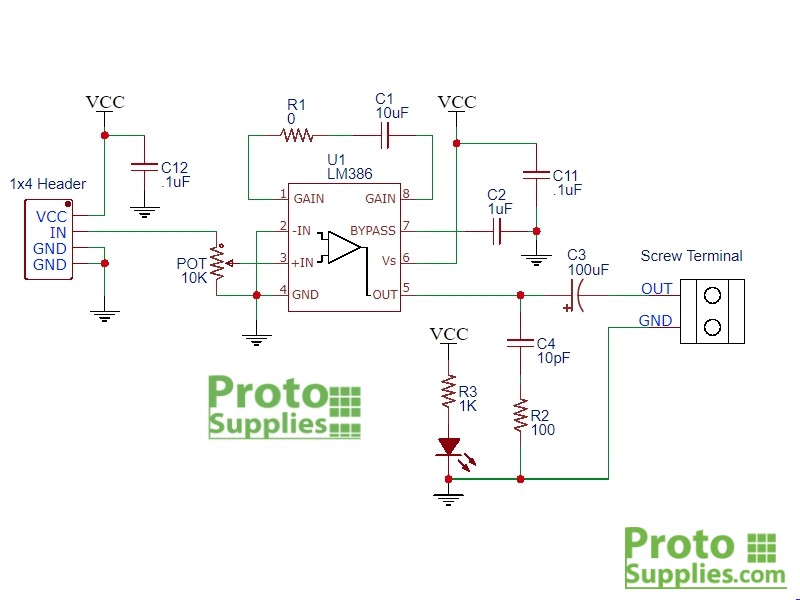
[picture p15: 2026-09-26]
pcb/references/lm386-schematic.jpg

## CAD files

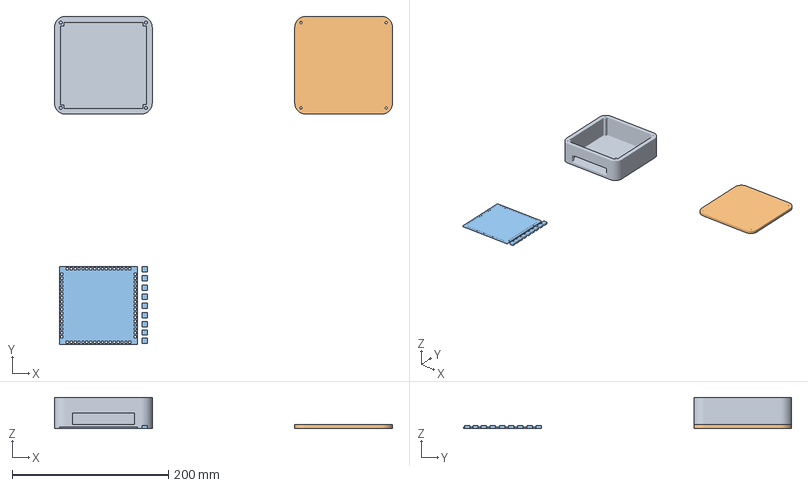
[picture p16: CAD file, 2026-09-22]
enclosure/K1 Adapter Box.3mf
432.2 x 419.7 x 40.0 mm
K1 Adapter Box Body.stl
K1 Adapter Box Lid.stl
Base Plate and Standoffs.stl

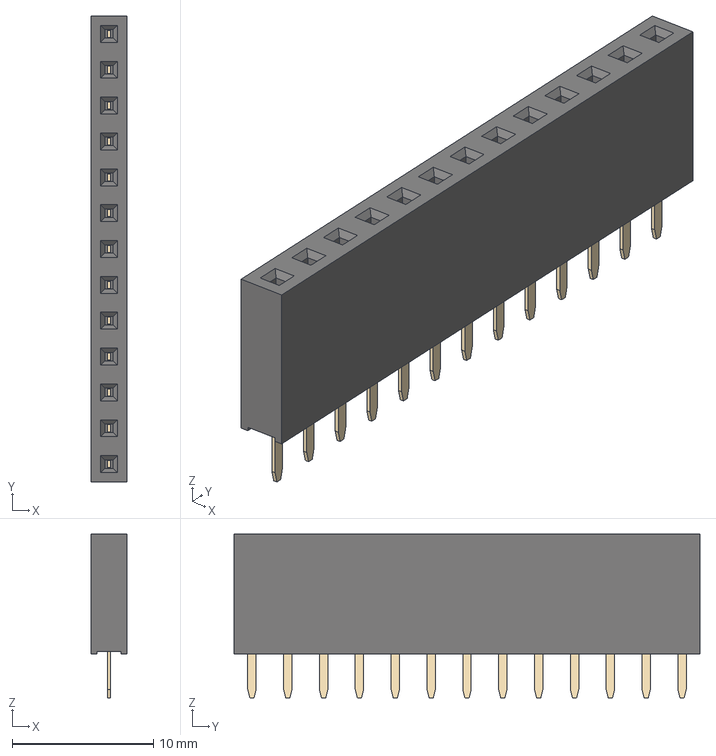
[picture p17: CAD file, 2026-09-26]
pcb/kicad/models/PinSocket_1x13_P2.54mm_Vertical.step
2.54 x 33.0 x 11.6 mm

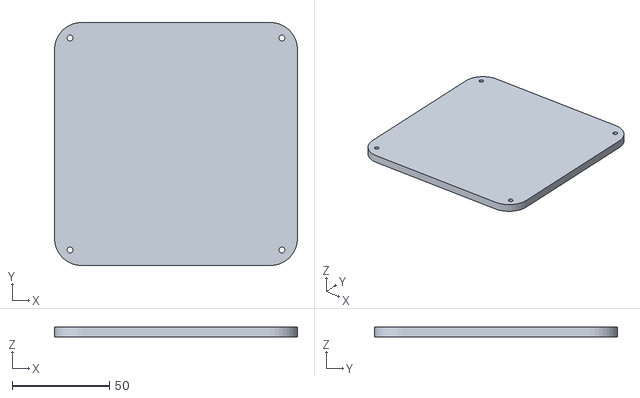
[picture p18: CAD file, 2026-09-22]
enclosure/K1 Adapter Box Lid.stl
125.0 x 125.0 x 5.00

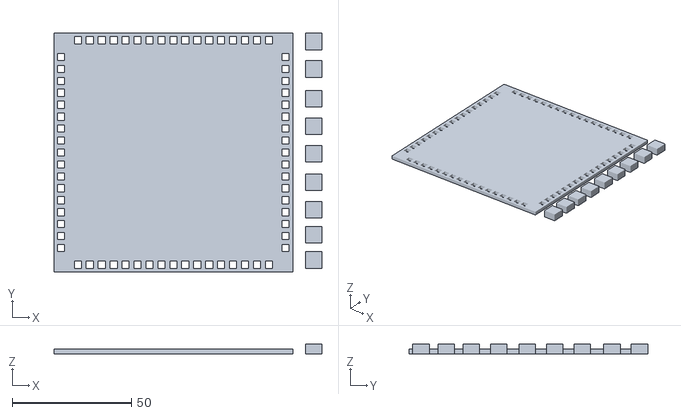
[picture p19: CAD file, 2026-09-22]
enclosure/Base Plate and Standoffs.stl
112.2 x 100.0 x 4.00

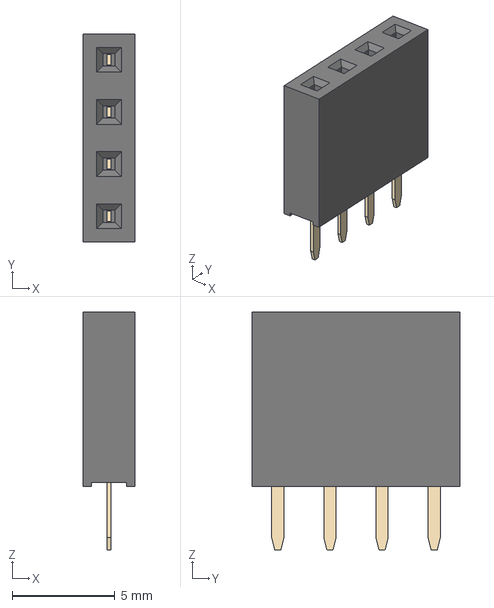
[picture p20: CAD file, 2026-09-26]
pcb/kicad/models/PinSocket_1x04_P2.54mm_Vertical.step
2.54 x 10.2 x 11.6 mm

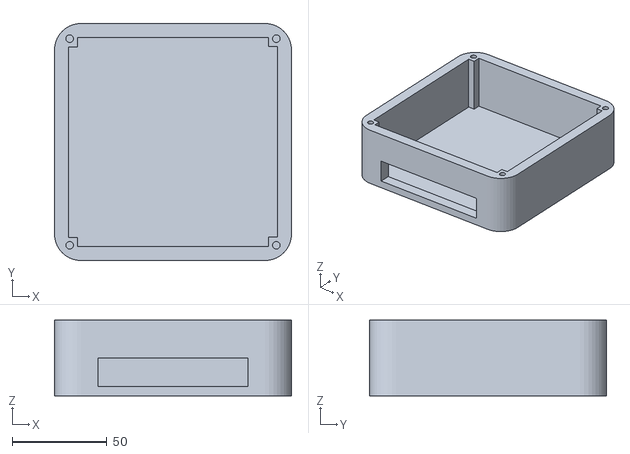
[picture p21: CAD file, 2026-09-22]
enclosure/K1 Adapter Box Body.stl
125.0 x 125.0 x 40.0

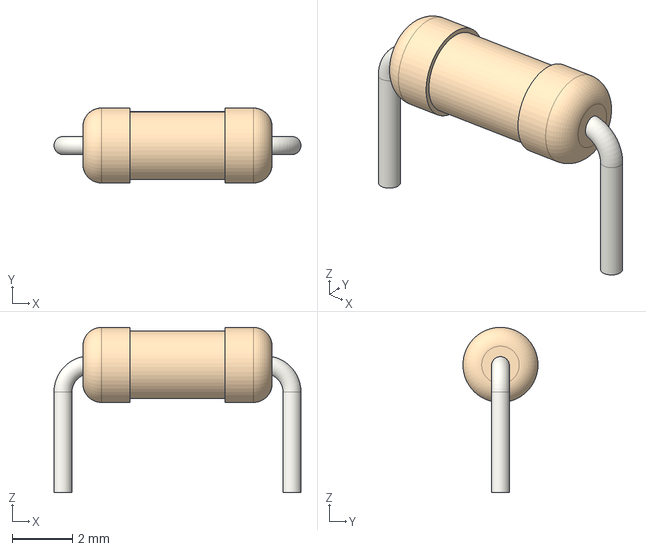
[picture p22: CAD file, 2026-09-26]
pcb/kicad/models/R_Axial_DIN0207_L6.3mm_D2.5mm_P7.62mm_Horizontal.step
8.22 x 2.50 x 5.50 mm

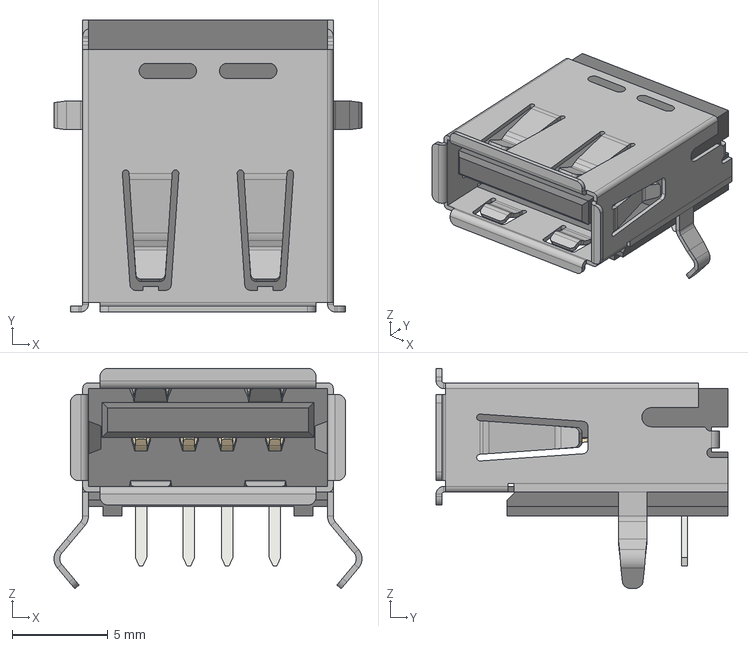
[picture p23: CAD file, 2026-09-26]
pcb/kicad/models/USB_A_Molex_67643_Horizontal.step
16.1 x 15.3 x 11.5 mm

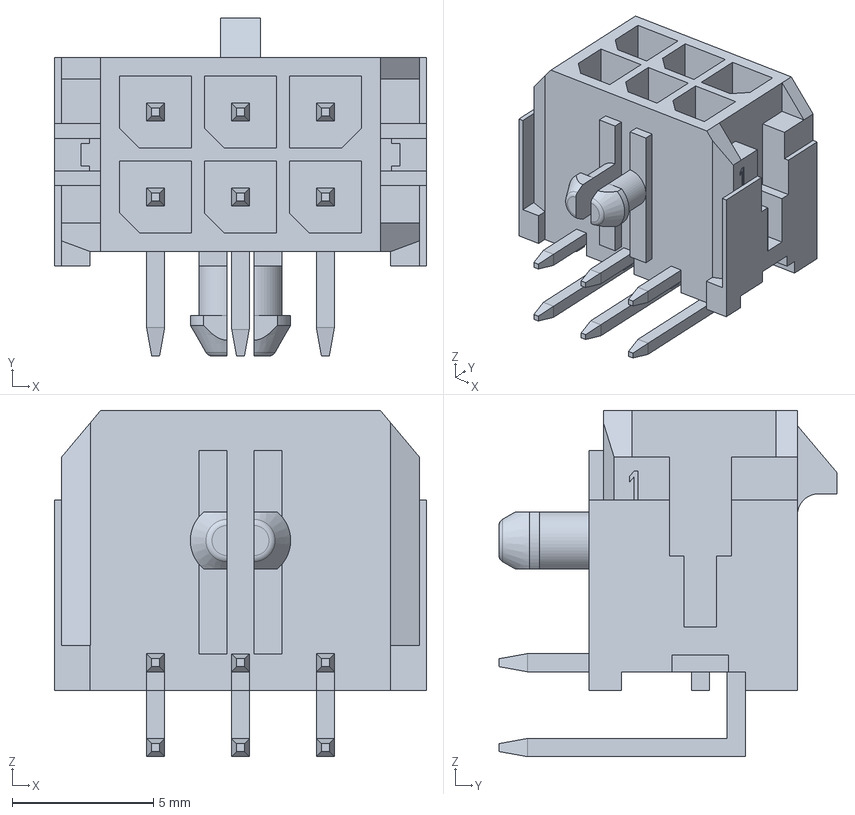
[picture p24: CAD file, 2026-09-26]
pcb/kicad/models/430450600.stp
13.2 x 11.9 x 12.2 mm

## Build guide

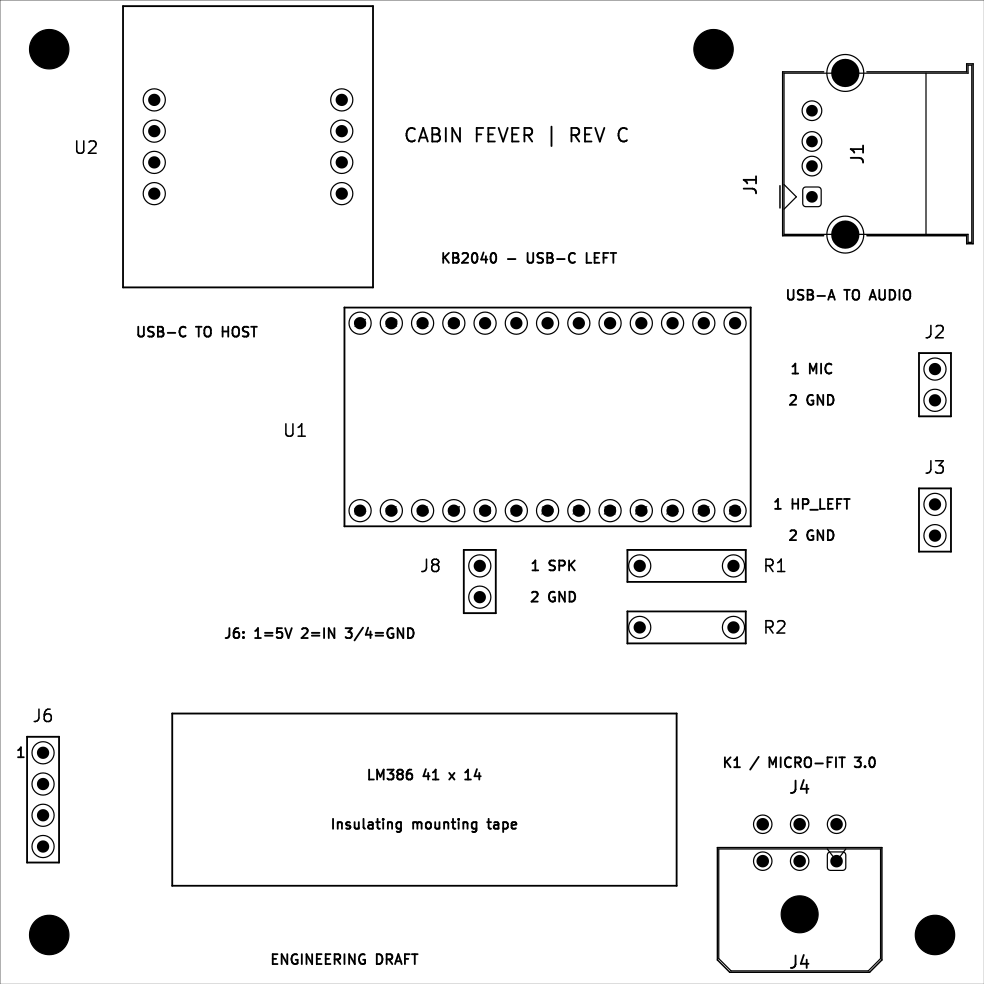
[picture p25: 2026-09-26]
pcb/preview/assembly.png

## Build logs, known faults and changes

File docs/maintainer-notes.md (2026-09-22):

# Maintainer notes

## Repository contents

This repository documents the USB K1 speaker-mic adapter, with the README serving as the main assembly guide.

- `firmware/code.py` supplies the button firmware. Its bindings are F13 and Ctrl+Space, with external input pull-ups enabled electrically and internal pull-ups disabled in software.
- The wiring diagram is supplied as SVG and PNG. It includes an optional 9 V amplifier annotation; the README documents the USB 5 V build and explains the USB power labels.
- `hardware/testing/` contains not-to-scale probe-placement diagrams for the two QHM22D resistance checks. Each is supplied as editable SVG and a PNG export, with the same contact pairs and expected readings as the testing table. Both exports were visually inspected.
- Firmware installation is covered in the README, with serial-console instructions in `docs/serial-console.md`.
- Prototype audio and repair results are the builder's reported observations.
- Firmware validation covers Python syntax and simulated debounce, held-key overlap, chord release, and recovery after a USB send error. It does not replace testing on CircuitPython and actual USB hosts.

## Photo inventory

| Repository file | Original upload | Use |
| --- | --- | --- |
| `cabin-fever-demo.jpg` | `IMG_8638.jpeg` | README hero |
| `finished-handset.jpg` | `IMG_8634.jpeg` | Complete assembly |
| `assembly.jpg` | `IMG_8630.jpeg` | Module layout |
| `enclosure-open.jpg` | `IMG_8631.jpeg` | Internal mounting |
| `enclosure-front.jpg` | `IMG_8636.jpeg` | Cable entry |
| `qhm22d-before.jpg` | `IMG_8586(1).jpeg` | Factory reversal |
| `qhm22d-after.jpg` | `IMG_8587.jpeg` | Repaired cable pads |

Photos are unaltered copies under descriptive filenames. `IMG_8585.jpeg` (the Amazon screenshot) is excluded. `IMG_8639.jpeg` is unused because its terminal screen includes unrelated project details; the Cabin Fever photo provides the application view.

## Documentation gaps

1. The `enclosure/` folder includes the body, lid, and mounting plate/standoff STLs, plus a Bambu Lab P1S 3MF project. See [enclosure notes](enclosure.md). Editable source CAD and exact fastener specifications remain to be documented.
2. Record the final USB audio adapter and connector/cable SKUs. The BOM gives functional requirements and a reference audio adapter.
3. Record the final working Claude Code / Windows Terminal / Teams configuration, including versions. Do not promote the Ctrl+Space example to a tested recipe without verifying press, hold, and release.

## License

The repository uses the [MIT License](../LICENSE), except for the adapted K1 accessory diagram, which retains its CC BY-SA 3.0 license. See the [README attribution](../README.md#k1-diagram-sources).

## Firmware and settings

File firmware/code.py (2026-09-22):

"""KB2040 USB PTT: D2 or BOOT holds F13; D3 holds Ctrl+Space.

Copy to CIRCUITPY/code.py. Install adafruit_hid in CIRCUITPY/lib.
D2/D3 require external pull-ups to 3.3V with the default settings below.
"""

import time

import board
import digitalio
import usb_hid
from adafruit_hid.keyboard import Keyboard
from adafruit_hid.keycode import Keycode


PTT1_KEY = Keycode.F13
PTT2_KEY = (Keycode.LEFT_CONTROL, Keycode.SPACE)
BOOT_ALIASES_PTT1 = True
USE_INTERNAL_PULLUPS = False  # External 10k pull-ups on D2/D3.
DEBOUNCE_SECONDS = 0.020
POLL_SECONDS = 0.002
LOG_CHANGES = True


def binding_keys(binding):
    return (binding,) if isinstance(binding, int) else tuple(binding)


class Button:
    def __init__(self, pin, key, pull_up):
        self.io = digitalio.DigitalInOut(pin)
        self.io.switch_to_input(pull=digitalio.Pull.UP if pull_up else None)
        self.keys = binding_keys(key)
        self.pressed = False
        self.candidate = not self.io.value
        self.changed_at = time.monotonic()

    def update(self, now):
        sample = not self.io.value
        if sample != self.candidate:
            self.candidate = sample
            self.changed_at = now
        if now - self.changed_at >= DEBOUNCE_SECONDS:
            self.pressed = self.candidate


def main():
    buttons = [
        Button(board.D2, PTT1_KEY, USE_INTERNAL_PULLUPS),
        Button(board.D3, PTT2_KEY, USE_INTERNAL_PULLUPS),
    ]
    if BOOT_ALIASES_PTT1:
        buttons.append(Button(board.BUTTON, PTT1_KEY, True))

    keyboard = Keyboard(usb_hid.devices)
    sent = None
    print("PTT ready.")

    try:
        while True:
            now = time.monotonic()
            for button in buttons:
                button.update(now)

            # Combine aliases before sending releases: either source can hold F13.
            desired = {
                key for button in buttons if button.pressed for key in button.keys
            }
            try:
                if sent is None:
                    keyboard.release_all()
                    sent = set()
                released = sent - desired
                pressed = desired - sent
                if released:
                    keyboard.release(*released)
                if pressed:
                    keyboard.press(*pressed)
                if LOG_CHANGES and desired != sent:
                    print(
                        "PTT1:",
                        "DOWN" if all(k in desired for k in binding_keys(PTT1_KEY)) else "up",
                        "PTT2:",
                        "DOWN" if all(k in desired for k in binding_keys(PTT2_KEY)) else "up",
                    )
                sent = desired
            except OSError:
                # Resynchronize the complete held state when USB is available again.
                sent = None
                time.sleep(0.100)

            time.sleep(POLL_SECONDS)
    finally:
        try:
            keyboard.release_all()
        except OSError:
            pass
        for button in buttons:
            button.io.deinit()


if __name__ == "__main__":
    main()

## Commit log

2026-09-22 Revise project README (#1)
    * docs: give the README a maker project narrative
    * Small edits.
    * docs: identify the Adafruit Perma-Proto board used in the build
    * docs: add high-level adapter block diagram
    * docs: replace Mermaid overview with mobile-friendly PNG
    * docs: explain the K1 connector before introducing the build
    * docs: explain common-ground amplification and the R1 gain modification
    * docs: explain keyboard emulation and KB2040 selection
    * docs: bring schematic and assembly photo together
    * Small wording updates.
    * More small fixes.
    * Removed more text.
    * simplified parts list
    * More wordsmithing.
    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
2026-09-22 Added enclosure STLs
    [Base Plate and Standoffs.stl, K1 Adapter Box Body.stl, K1 Adapter Box Lid.stl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]
2026-09-22 Document enclosure print files and P1S project (#3)
    * Document enclosure STLs and Bambu Lab P1S print project
2026-09-26 Astra's work on a PCB
    [430450600.stp, PinSocket_1x04_P2.54mm_Vertical.step, PinSocket_1x13_P2.54mm_Vertical.step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]

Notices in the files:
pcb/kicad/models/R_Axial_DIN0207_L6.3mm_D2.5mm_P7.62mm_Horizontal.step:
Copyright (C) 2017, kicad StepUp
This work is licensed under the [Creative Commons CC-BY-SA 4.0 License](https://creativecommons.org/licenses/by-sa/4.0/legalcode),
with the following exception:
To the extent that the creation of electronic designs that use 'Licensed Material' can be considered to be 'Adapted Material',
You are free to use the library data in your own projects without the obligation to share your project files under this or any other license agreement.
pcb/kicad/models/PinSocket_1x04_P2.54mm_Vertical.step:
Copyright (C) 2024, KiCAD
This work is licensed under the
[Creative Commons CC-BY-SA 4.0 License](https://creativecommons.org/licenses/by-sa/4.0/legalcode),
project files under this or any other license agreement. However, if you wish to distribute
